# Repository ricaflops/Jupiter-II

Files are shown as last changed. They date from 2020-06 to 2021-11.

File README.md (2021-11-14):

# Jupiter-II
**Another Jupiter Ace computer clone**

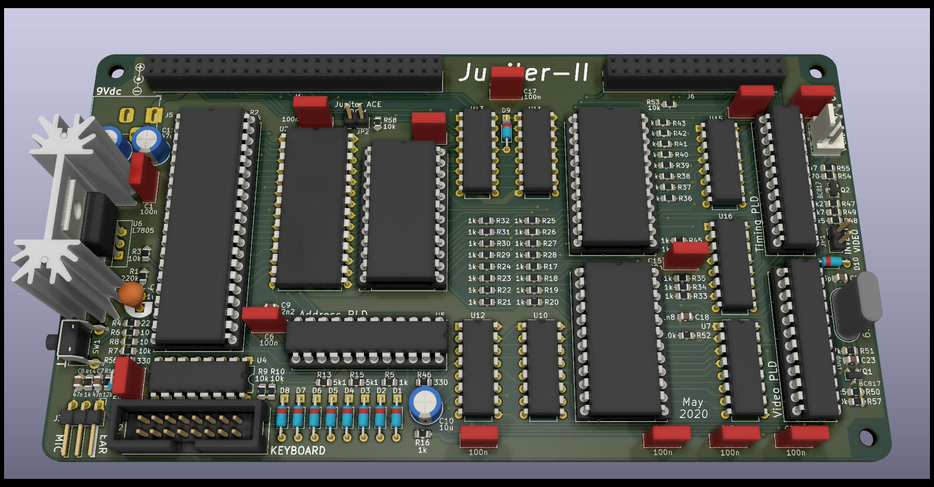
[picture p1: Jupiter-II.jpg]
Jupiter-II KiCAD 3D view

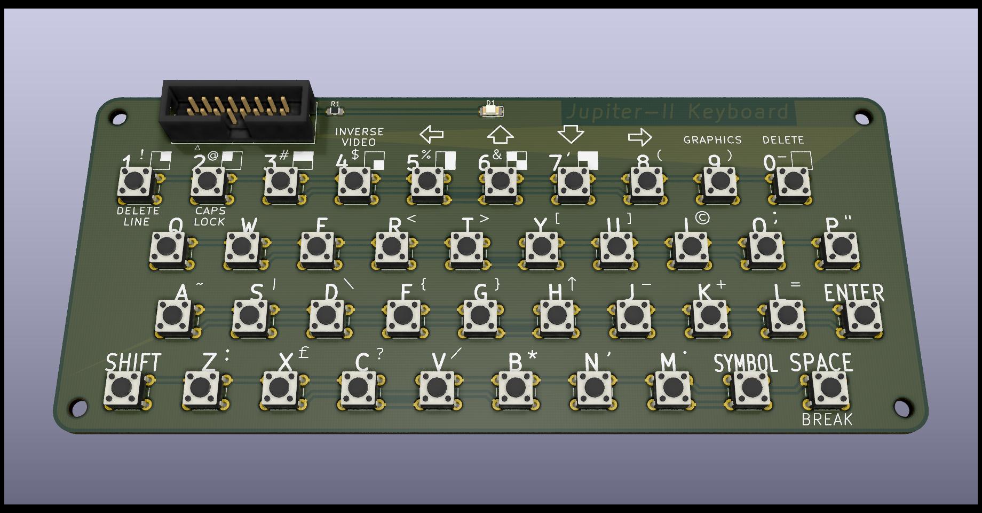
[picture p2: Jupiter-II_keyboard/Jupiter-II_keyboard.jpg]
Jupiter-II keyboard KiCAD 3D view


## Main differences from the original Jupiter Ace
* Buffered composite video output
* Reset button
* Inversed video jumper selection
* Two screen pages and two character sets area (selectable at the video expansion connector)
* Reduced chip count with PLDs replacing several TTL logic
* Additional signals in expansion connectors

For more information on the original Jupiter Ace computer and an extensive software collection visit [The Jupiter Ace Archive](http://jupiter-ace.co.uk/)

## The Jupiter-II Expansion
See the [Jupiter-II Expansion](https://github.com/ricaflops/Jupiter-II-Expansion) project for adding:
- Video Colour
- Programmable Sound Generator
- 128K paged RAM
- Serial Interface
- FORTH vocabulary extension (Color, Memory Paging, Sound Generator, etc.)

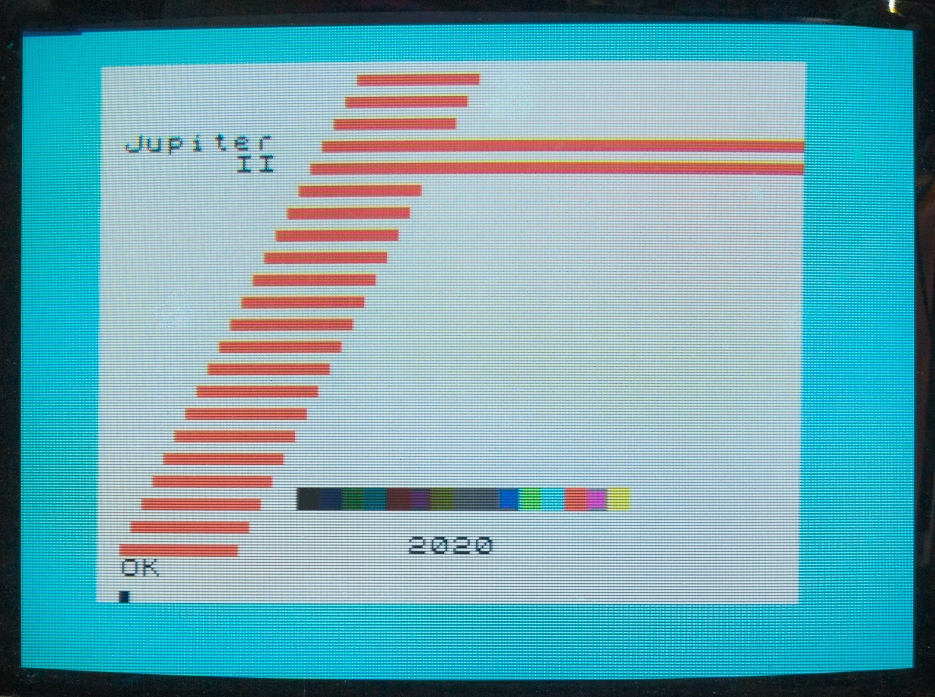
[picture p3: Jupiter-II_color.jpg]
Jupiter-II color expansion


# Jumper Settings

Inverse Video Jumper
- Jumper installed: Black text on white background (inversed)
- Jumper removed: White text on black background (default)

ROM image selection Jumper
- Jumper installed: Original Jupiter Ace 8K ROM image
- Jumper removed: Boot with the [Jupiter-II Expansion](https://github.com/ricaflops/Jupiter-II-Expansion)

The original Jupiter Ace 8K ROM image can be found at [The Jupiter Ace Archive](https://www.jupiter-ace.co.uk/).

# Connections

### Power Supply
Connect a 7.5Vdc to 9 Vdc x 1A power supply. Center pin is positive.

### A/V output
- pin 1: Audio Output (BEEP)
- pin 2: Common
- pin 3: Composite Video Output

The video standard is **60Hz NTSC** compatible but converting to 50Hz PAL by recoding the PLDs shall not be too difficult.

### Tape I/O
- pin 1: MIC output (for LOADing)
- pin 2: Common
- pin 3: EAR input (for SAVEing)

### Expansion
50 pin header connector (2x25 female).
Similar layout as the original Jupiter Ace with additional pins "-ROMSL" and "SPEAKER"

* pin 1:**GND** , pin 2:**GND**
* pin 3:**-INT** , pin 4:**GND**
* pin 5:**-NMI** , pin 6:**+9Vdc**
* pin 7:**-HALT** , pin 8:**+5Vdc**
* pin 9:**-MREQ** , pin 10:**-CLK**
* pin 11:**-IORQ** , pin 12:**A11**
* pin 13:**-RD** , pin 14:**A12**
* pin 15:**-WR** , pin 16:**A13**
* pin 17:**-BUSACK** , pin 18:**A14**
* pin 19:**-WAIT** , pin 20:**A15**
* pin 21:**-BUSRQ** , pin 22:**D4**
* pin 23:**-RESET** , pin 24:**D3**
* pin 25:**-M1** , pin 26:**D5**
* pin 27:**-RFSH** , pin 28:**A2**
* pin 29:**A6** , pin 30:**A10**
* pin 31:**A5** , pin 32:**A9**
* pin 33:**A4** , pin 34:**A8**
* pin 35:**A3** , pin 36:**A7**
* pin 37:**A1** , pin 38:**A0**
* pin 39:**D0** , pin 40:**D1**
* pin 41:**D2** , pin 42:**D6**
* pin 43:**D7** , pin 44:**-WE**
* pin 45:(n.c.) , pin 46:(n.c.)
* pin 47:**-ROMSL** , pin 48:**SPEAKER**
* pin 49:(n.c.) , pin 50:(n.c.)

(n.c.) means not connected

**-ROMSL** *(in)* Disables internal ROM chip when connected to +5V

**SPEAKER** *(out)* TTL level Speaker signal (BEEP)

### Video Expansion
30 pins header connector (2x15 female).
Similar layout as the original Jupiter Ace with some additional pins.

* pin 1:**VA3** , pin 2:**VA0**
* pin 3:**VA5** , pin 4:**VA4**
* pin 5:**VD2** , pin 6:**VD3**
* pin 7:**VD1** , pin 8:**VD4**
* pin 9:**VA6** , pin 10:**VD0**
* pin 11:**VA2** , pin 12:**VD7**
* pin 13:**-VRAMWR** , pin 14:**VD5**
* pin 15:**VA8** , pin 16:**VA7**
* pin 17:**VA9** , pin 18:**VA1**
* pin 19:**VD6** , pin 20:**-VLOAD**
* pin 21:**+5Vdc** , pin 22:**GND**
* pin 23:**-CPAGE** , pin 24:**-SPAGE**
* pin 25:**-SCRRAM** , pin 26:**-VSYNC**
* pin 27:**BORDER** , pin 28:**-HSYNC**
* pin 29:**LUMA** , pin 30:**BLANK**

**-VRAMWR** *(out)* Video RAM write enable

**-CPAGE** *(in)* Character Generator page selection

**-SPAGE** *(in)* Screen page selection

**-SCRRAM** *(out)* Screen RAM enabled

**-VSYNC** *(out)* Vertical Video Synch

**-HSYNC** *(out)* Horizontal Video Synch

**LUMA** *(out)* Video Luminance

**BLANK** *(out)* Video Blanking (retrace blanking)

## Tools used & file formats
* Designed with [Kicad](https://www.kicad.org/)
* Programmable Logic Devices coded in CUPL language (compiled with WinCupl available for free at [Microchip](https://www.microchip.com/))

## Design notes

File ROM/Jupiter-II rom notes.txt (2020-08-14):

Jupiter-II 16K ROM contains two images:
- Lower  8K: Original Jupiter Ace ROM image.
- Higher 8K: Patched image to call Expansion ROM initialization.

A board jumper is provided to select which image to boot:
- Jumpter installed: Original ROM image. Do not boot the Expansion ROM.
- Jumper removed: Patched ROM image. Includes Expansion ROM booting.

The patch is applied at address $008E of original ROM image:
    008E: C3 00 C0 00

Original code:
    008E: ED 56      IM 1      ; Set Interrupt mode 1
    0090: 18 09      JR $009B  ; Quit to FORTH

Patched code:
    008E: C3 00 C0   JP $C000  ; Redirect to XROM code
    0091: 00         NOP       ; Do nothing

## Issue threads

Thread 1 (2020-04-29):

Video

flypie, 2020-04-29:
Hi,
I had a look at your Ace and it looks very good. I'm doing a similar project I did find that I had to boost the composite sign before I could get a monitor to sync I used this circuit. https://jupiter-ace.co.uk/hardware_ebvdoboard.html I'm thinking of doing the similar for the audio out rather than use a speaker, not sure of what needed to get impedance correct.

ricaflops, 2020-04-29:
Hi,Thank You for the message.
I'm still waiting for the PCB to arrive from JLCPCB. It should take another month or two due to the current mail delays from China. Then I'll have several hours of fun validating those CUPL codes and making it work!

I did some protoboarding and tested the video circuit with a studio grade SONY video monitor and it worked fine. Should have experimented with a regular TV/monitor also before ordering the PCB. Thanks for the advice.

This project is intended to be a base for experimenting on Jupiter Ace expansions. I have some ideas to try and the type of expansion connectors chosen and the inclusion of more video signals shall make it easier to experiment on protoboard.
Many years ago I build a Jupiter Ace using wire-wrapping. You can check the actual pictures of it on the Jupiter Ace resource site. It was ugly but worked. Now that I'm reviving interest on this computer it is a good time to build it more adequately.
Just saw your Ace-2019 project in Github. Great work!
I specially like the use of dual port RAMs in video circuit.

Best regards,Ricardo.

    Em quarta-feira, 29 de abril de 2020 14:01:12 BRT, flypie <notifications@github.com> escreveu:

Hi,
I had a look at your Ace and it looks very good. I'm doing a similar project I did find that I had to boost the composite sign before I could get a monitor to sync I used this circuit. https://jupiter-ace.co.uk/hardware_ebvdoboard.html I'm thinking of doing the similar for the audio out rather than use a speaker, not sure of what needed to get impedance correct.

—
You are receiving this because you are subscribed to this thread.
Reply to this email directly, view it on GitHub, or unsubscribe.

flypie, 2020-04-30:
Hi

I order some SRAM from Wuhan earlier January, got it last week. I'm using the dual-port so that I don't have to use multiples of the video speed for the CPU.  There is the possibility with the faster Z80s to bypass the dived by 2 on the CPU and use the raw clock. With a few mods it should be possible to double the crystal and then dive by 2 for the video. The ACE3NOKB version I'm starting testing today will allow me to play with this using jumpers.
Your use of the 74HCT4040 is great I think I will do the same.
Are you going to stick with the DIP Z80? I've decided to use QFP for the CPU and ROM to save space and put 64k of RAM on the board using 2  IS61C256AL-12JLI.

ricaflops, 2020-05-01:
Hi,My option on vintage components (DIP Z80,ROM,RAM,etc) was to reuse as much components from my old inventary as I can, and keep costs low. The use of those old GALs was also motivated to easy the PCB design.

At this moment I want a working and compatible Jupiter Ace to experiment on interfacing ..and allow some nostalgic experience running those games on a real hardware as well.

I specifically want to experiment on sound with AY-3-8910, an UART to load/save via USB/RS232, color video, and test some ideas on memory paging and extended vocabulary ROM. Perhaps approaching something like an imaginary ZX-Spectrum competitor or what would be a backward compatible second generation Ace at that time. An Ace-Rainbow or Jupiter-Colour?

The clever approach in your project of freeing the video RAM from CPU syncing makes it possible I think to easily generate a VGA or HDMI video signal and use modern monitors. And perhaps even enable higher resolution video by increasing video RAM size and some changes in the original ROM code.
Your project is very inspiring for me and there is a lot to learn from it. Keep the nice work.

-RL
    Em quinta-feira, 30 de abril de 2020 10:11:15 BRT, flypie <notifications@github.com> escreveu:

Hi

I order some SRAM from Wuhan earlier January, got it last week. I'm using the dual-port so that I don't have to use multiples of the video speed for the CPU. There is the possibility with the faster Z80s to bypass the dived by 2 on the CPU and use the raw clock. With a few mods it should be possible to double the crystal and then dive by 2 for the video. The ACE3NOKB version I'm starting testing today will allow me to play with this using jumpers.
Your use of the 74HCT4040 is great I think I will do the same.
Are you going to stick with the DIP Z80? I've decided to use QFP for the CPU and ROM to save space and put 64k of RAM on the board using 2 IS61C256AL-12JLI.

—
You are receiving this because you commented.

Reply to this email directly, view it on GitHub, or unsubscribe.

flypie, 2020-05-03:
Hi

The recreating the ace is what I did first to make sure that I know how it all worked.

It is worth looking at the Z180 as it has an MMU inboard and it is still made by Zilog it would mean ROM changes to handle the interrupts. But with a 1Meg address space placing a 64k for VGA will out of the base 64k and paging the sections in to write to them would make sense. It would also mean that it might be possible to reduce the CPU VDG conflict.

For other expansion, it might be worth looking at[ PCMIA/Compact flash](https://en.wikipedia.org/wiki/PC_Card). It uses 5v TTL levels. Someone has done some work on [this ](https://z80project.wordpress.com/2015/07/06/z80-8-bit-compact-flash-card-interface-part-1/).

I'm beginning to think the best place for any ROM expansion is the top 8K to avoid having to rewrite the tape loader.

Are you aware of [SymbOS](https://en.wikipedia.org/wiki/SymbOS) The base hardware requirements might be a good target point?

I'm glad you find the project useful it was my hope to make it easier to design and build their own machines from readily available components.

ricaflops, 2020-05-04:
Thanks for the suggestions on Z180. will read the docs.

I agree on the ROM expansion position at the highest addresses.Lower addresses shall be RAM for the user FORTH dictionary to grown into and to keep some compatibility with the original Ace.

I am planning for the following memory organization for a 128K RAM + 16K ROM expansion:
(ASCII diagram follows)

       pg0   pg1   pg2   pg3  
    -|-----|-----|-----|-----|
FFFF | 16K |     |     |     |
C000 | ROM | 32K | 32K | 32K |
    -+-----| RAM | RAM | RAM |
BFFF | 16K | pg1 | pg2 | pg3 |
8000 | RAM |     |     |     |
    -+-----+-----+-----+-----|
7FFF |        Fixed          |
4000 |       16K RAM         |
    -+-----------------------|
3FFF |   (unexpanded Ace)    |
0000 |_______________________|

That gives a good fixed 16K RAM (non-paged) contiguous space for the user FORTH dictionary, a page of 16K RAM + 16K ROM, and more 3 pages of 32K RAM.

The plan is use the available two 8-bit I/O ports of AY-3-8910 sound generator for memory paging and screen colour register.
Port A: Screen colour INK/PAPER registers (4-bit each)
Port B: Memory paging (2-bits), Screen paging (1-bit), Charset page (1-bit), (remaining 4-bit to be defined yet)

Never looked at SymbOS before. I will check that.

About the audio output impedance. I never thinked too much on that.. lazy of me!
But I can remedy that.

The Wikipedia https://en.wikipedia.org/wiki/Line_level states that a typical consumer audio equipment line input impedance is around 10k ohms and the nominal amplitude is 0.89Vpp full range.

TTL LS family output impedance can be estimated around 100 ohm or so.
That allow us to reduce the TTL 5Vpp to a compatible 0.88Vpp using a 4.7K+1k voltage divider without a hard load on TTL.

A decoupling capacitor in series is needed as a high-pass filter to block DC current.
That filter cut-off frequency (-3dB point) is: f = 1/(2*pi*R*C).
Lets choose that frequency to at least 2Hz. That is one decade below the average hearing threshold of 20Hz.
Assuming the 10K ohm as the line input impedance: C = 1/(2*pi*10k*2) = 7.96uF (minimum)
I will choose 10uF.(ASCII diagram follows)
                        10uF
From TTL----[4.7k]---+---|(---- to Audio amplifier
                     |  +
     GND----[ 1k ]---+

Just did a lab test with a function generator and a small amplifier. Worked fine with a nice flat response from 10Hz and above.
May increase that 4.7k resistor to reduce volume. Maybe a 6.8k would result in a softer audio.

The EAR and MIC circuits also deserves better attention as it was originally designed to work with very different audio lines. Working on that too.

    Em domingo, 3 de maio de 2020 10:48:36 BRT, flypie <notifications@github.com> escreveu:

Hi

The recreating the ace is what I did first to make sure that I know how it all worked.

It is worth looking at the Z180 as it has an MMU inboard and it is still made by Zilog it would mean ROM changes to handle the interrupts. But with a 1Meg address space placing a 64k for VGA will out of the base 64k and paging the sections in to write to them would make sense. It would also mean that it might be possible to reduce the CPU VDG conflict.

For other expansion, it might be worth looking at PCMIA/Compact flash. It uses 5v TTL levels. Someone has done some work on this .

I'm beginning to think the best place for any ROM expansion is the top 8K to avoid having to rewrite the tape loader.

Are you aware of SymbOS The base hardware requirements might be a good target point?

I'm glad you find the project useful it was my hope to make it easier to design and build their own machines from readily available components.

—
You are receiving this because you commented.

Reply to this email directly, view it on GitHub, or unsubscribe.

flypie, 2020-05-04:
Hi

Thanks for the audio info, I do not get on with analogue.

Someone has done this. The ROM model is good and I the Video Model, only using one dual-port RAM is a lot cheaper.

https://www.tindie.com/products/tynemouthsw/minstrel-4th-z80-computer-kit/

ricaflops, 2020-05-11:
Board was received two days ago and hardware were tested/debugged.
Updated circuit uploaded. It includes some important corrections and a better/robust video output.
Thanks for the suggestion.And yes, that tynemouthsw product is very well thought. I like that they kept software compatibility.

    Em segunda-feira, 4 de maio de 2020 18:30:57 BRT, flypie <notifications@github.com> escreveu:

Hi

Thanks for the audio info, I do not get on with analogue.

Someone has done this. The ROM model is good and I the Video Model, only using one dual-port RAM is a lot cheaper.

https://www.tindie.com/products/tynemouthsw/minstrel-4th-z80-computer-kit/

—
You are receiving this because you commented.

Reply to this email directly, view it on GitHub, or unsubscribe.

flypie, 2020-05-11:
Hi,
Good to hear.

John BradleyTel: 07896 839635Skype: flypie125 125B Grove StreetEdge Hill Liverpool L7 7AF

    On Monday, 11 May 2020, 03:42:57 BST, Ricardo Fernandes Lopes <notifications@github.com> wrote:

Board was received two days ago and hardware were tested/debugged.
Updated circuit uploaded. It includes some important corrections and a better/robust video output.
Thanks for the suggestion.And yes, that tynemouthsw product is very well thought. I like that they kept software compatibility.

 Em segunda-feira, 4 de maio de 2020 18:30:57 BRT, flypie <notifications@github.com> escreveu:

Hi

Thanks for the audio info, I do not get on with analogue.

Someone has done this. The ROM model is good and I the Video Model, only using one dual-port RAM is a lot cheaper.

https://www.tindie.com/products/tynemouthsw/minstrel-4th-z80-computer-kit/

—
You are receiving this because you commented.

Reply to this email directly, view it on GitHub, or unsubscribe.
—
You are receiving this because you authored the thread.
Reply to this email directly, view it on GitHub, or unsubscribe.

Closed 2020-05-11.

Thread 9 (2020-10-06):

.Schematic depends on missing libraries

MrBlinky, 2020-10-06:
opening a schematic reports missing libraries:

rfl_memory.lib
rfl_pld.lib

Request: Export schematic to PDF using plot for easy reference

ricaflops, 2020-10-06:
extra library and PDF schematic uploaded

ricaflops, 2020-10-06:
Hi, Mr.Blinky
Library and PDF schematic uploaded.
Thank you!Ricardo

    Em terça-feira, 6 de outubro de 2020 07:36:00 BRT, Mr.Blinky <notifications@github.com> escreveu:

opening a schematic reports missing libraries:

rfl_memory.lib
rfl_pld.lib

Request: Export schematic to PDF using plot for easy reference

—
You are receiving this because you are subscribed to this thread.
Reply to this email directly, view it on GitHub, or unsubscribe.

MrBlinky, 2020-10-07:
Hi Ricardo,

Thank you for adding the library files and schematics.

Closed 2020-10-06.

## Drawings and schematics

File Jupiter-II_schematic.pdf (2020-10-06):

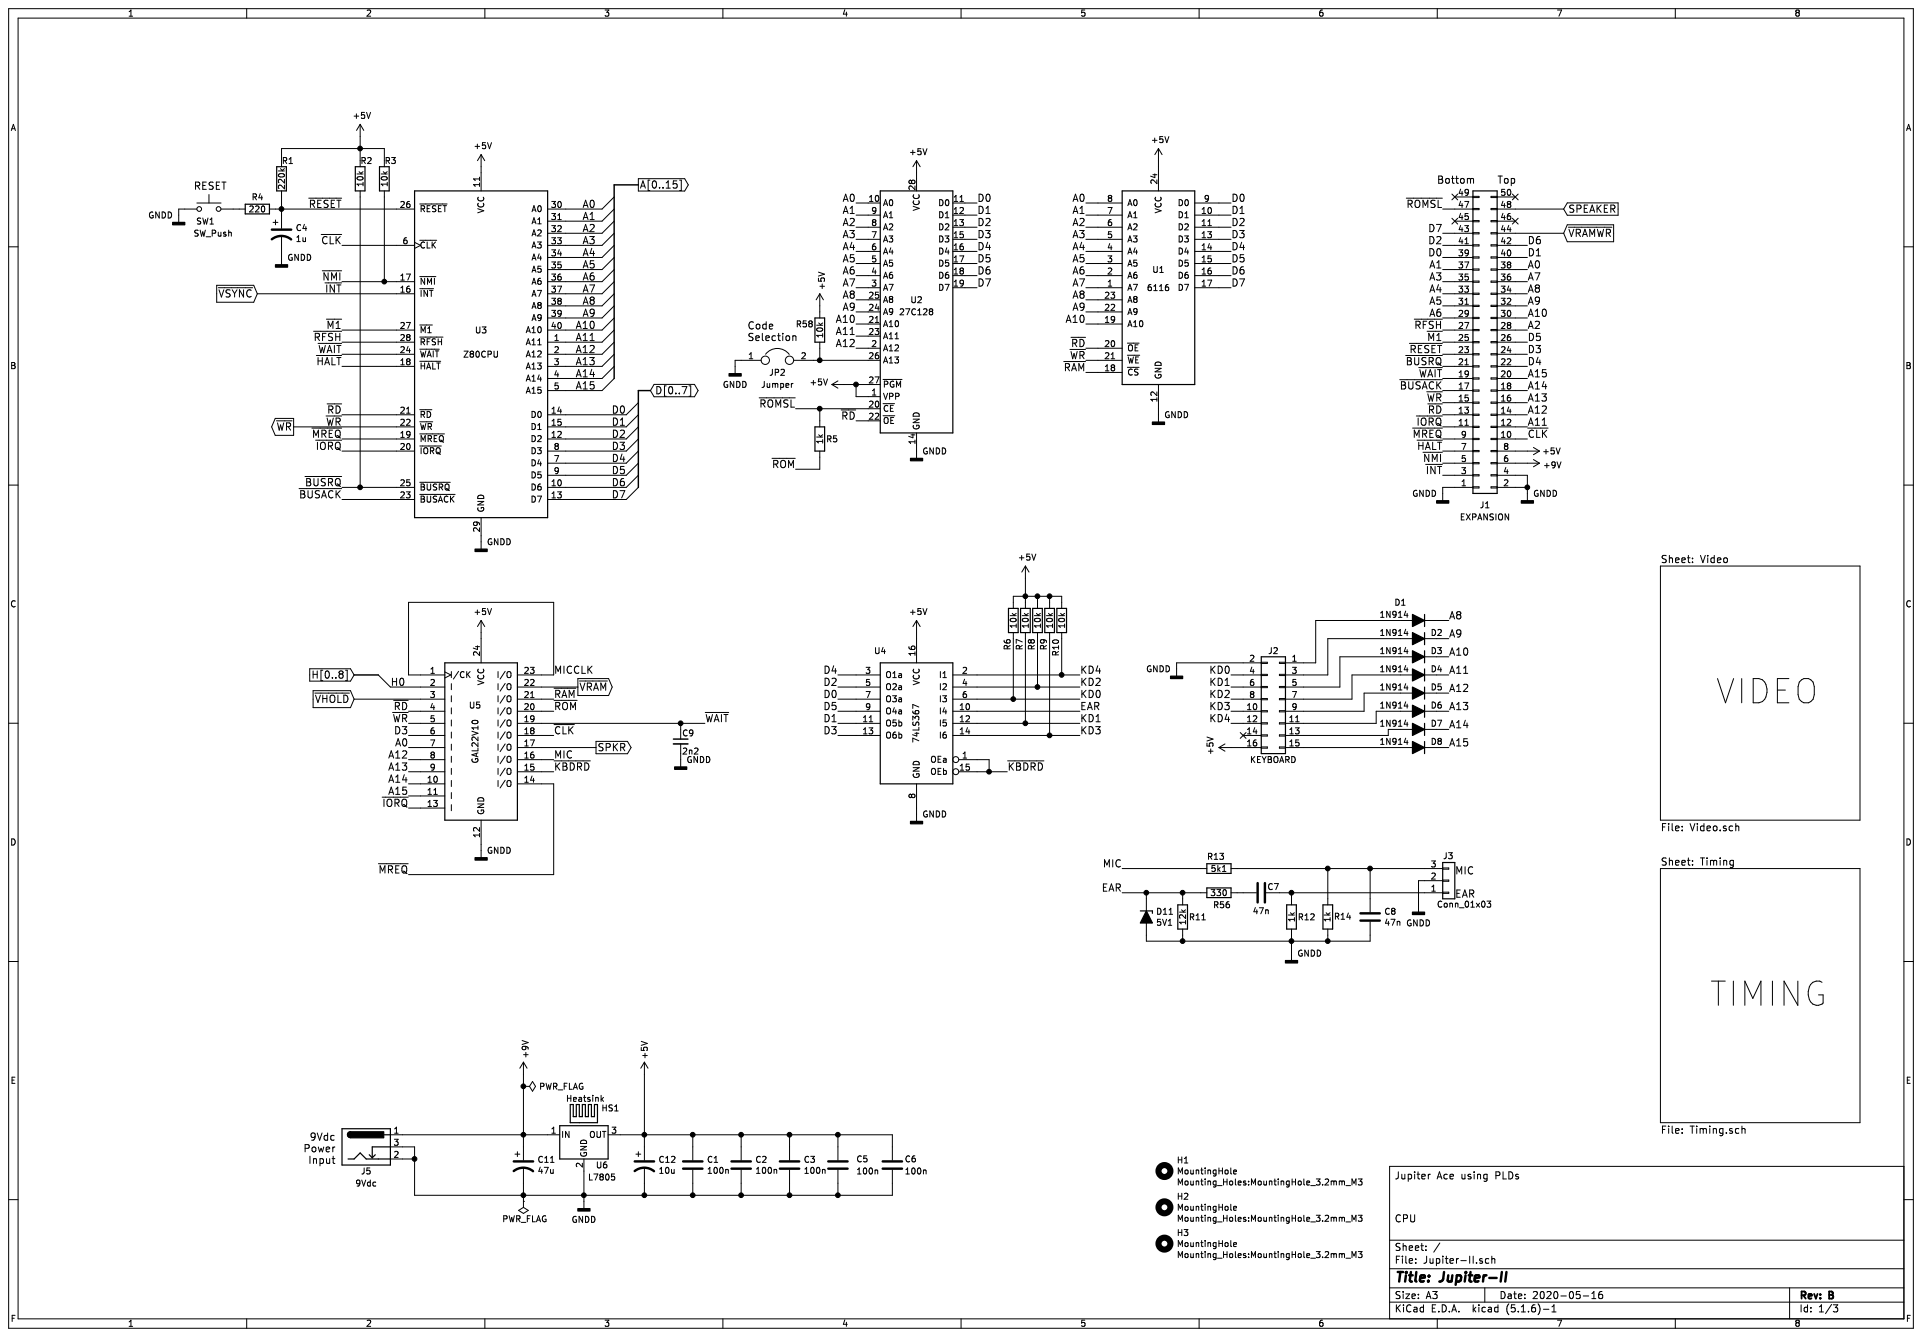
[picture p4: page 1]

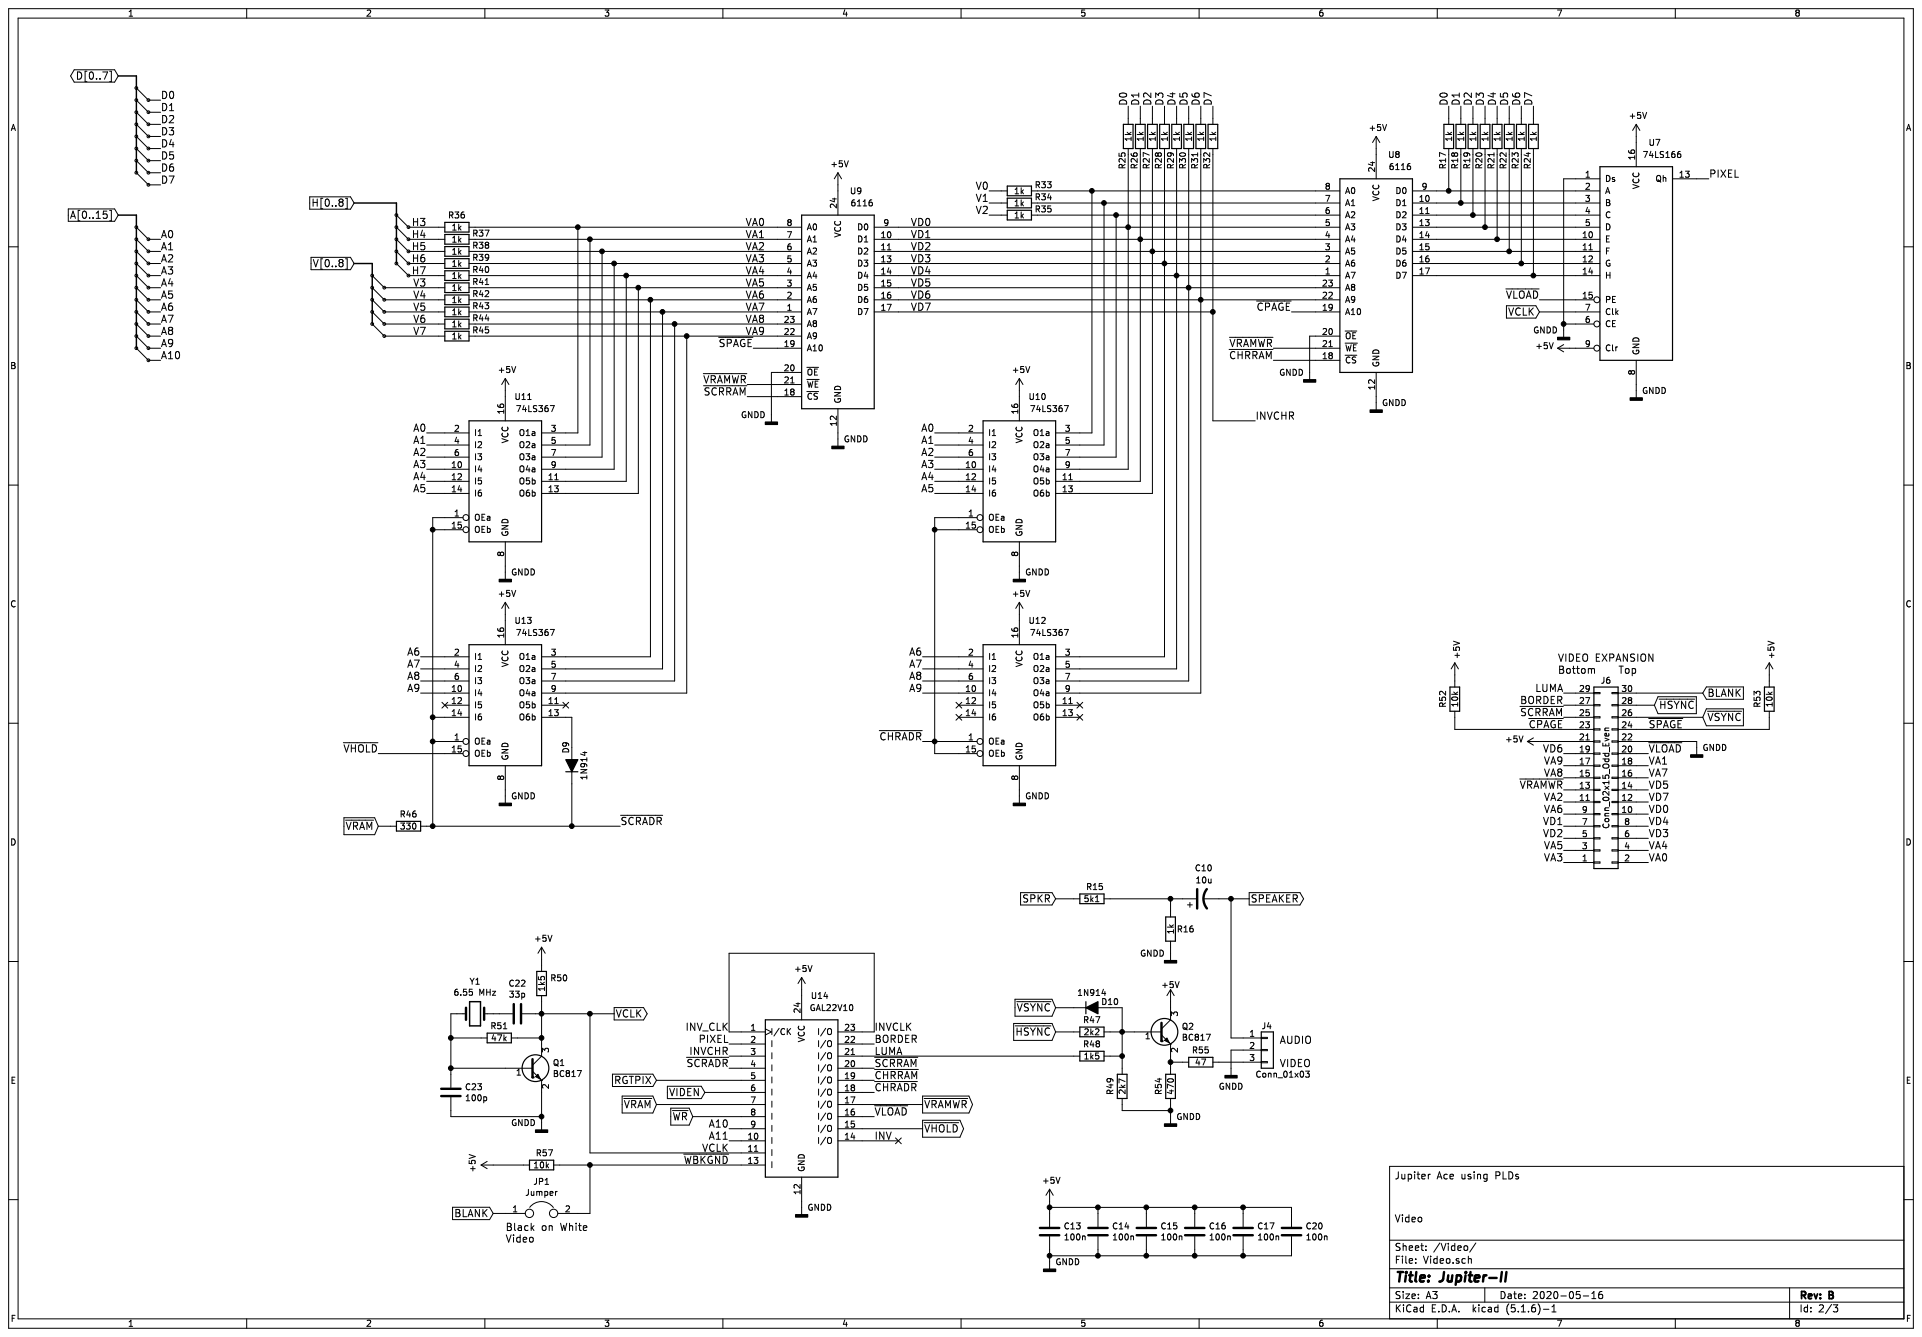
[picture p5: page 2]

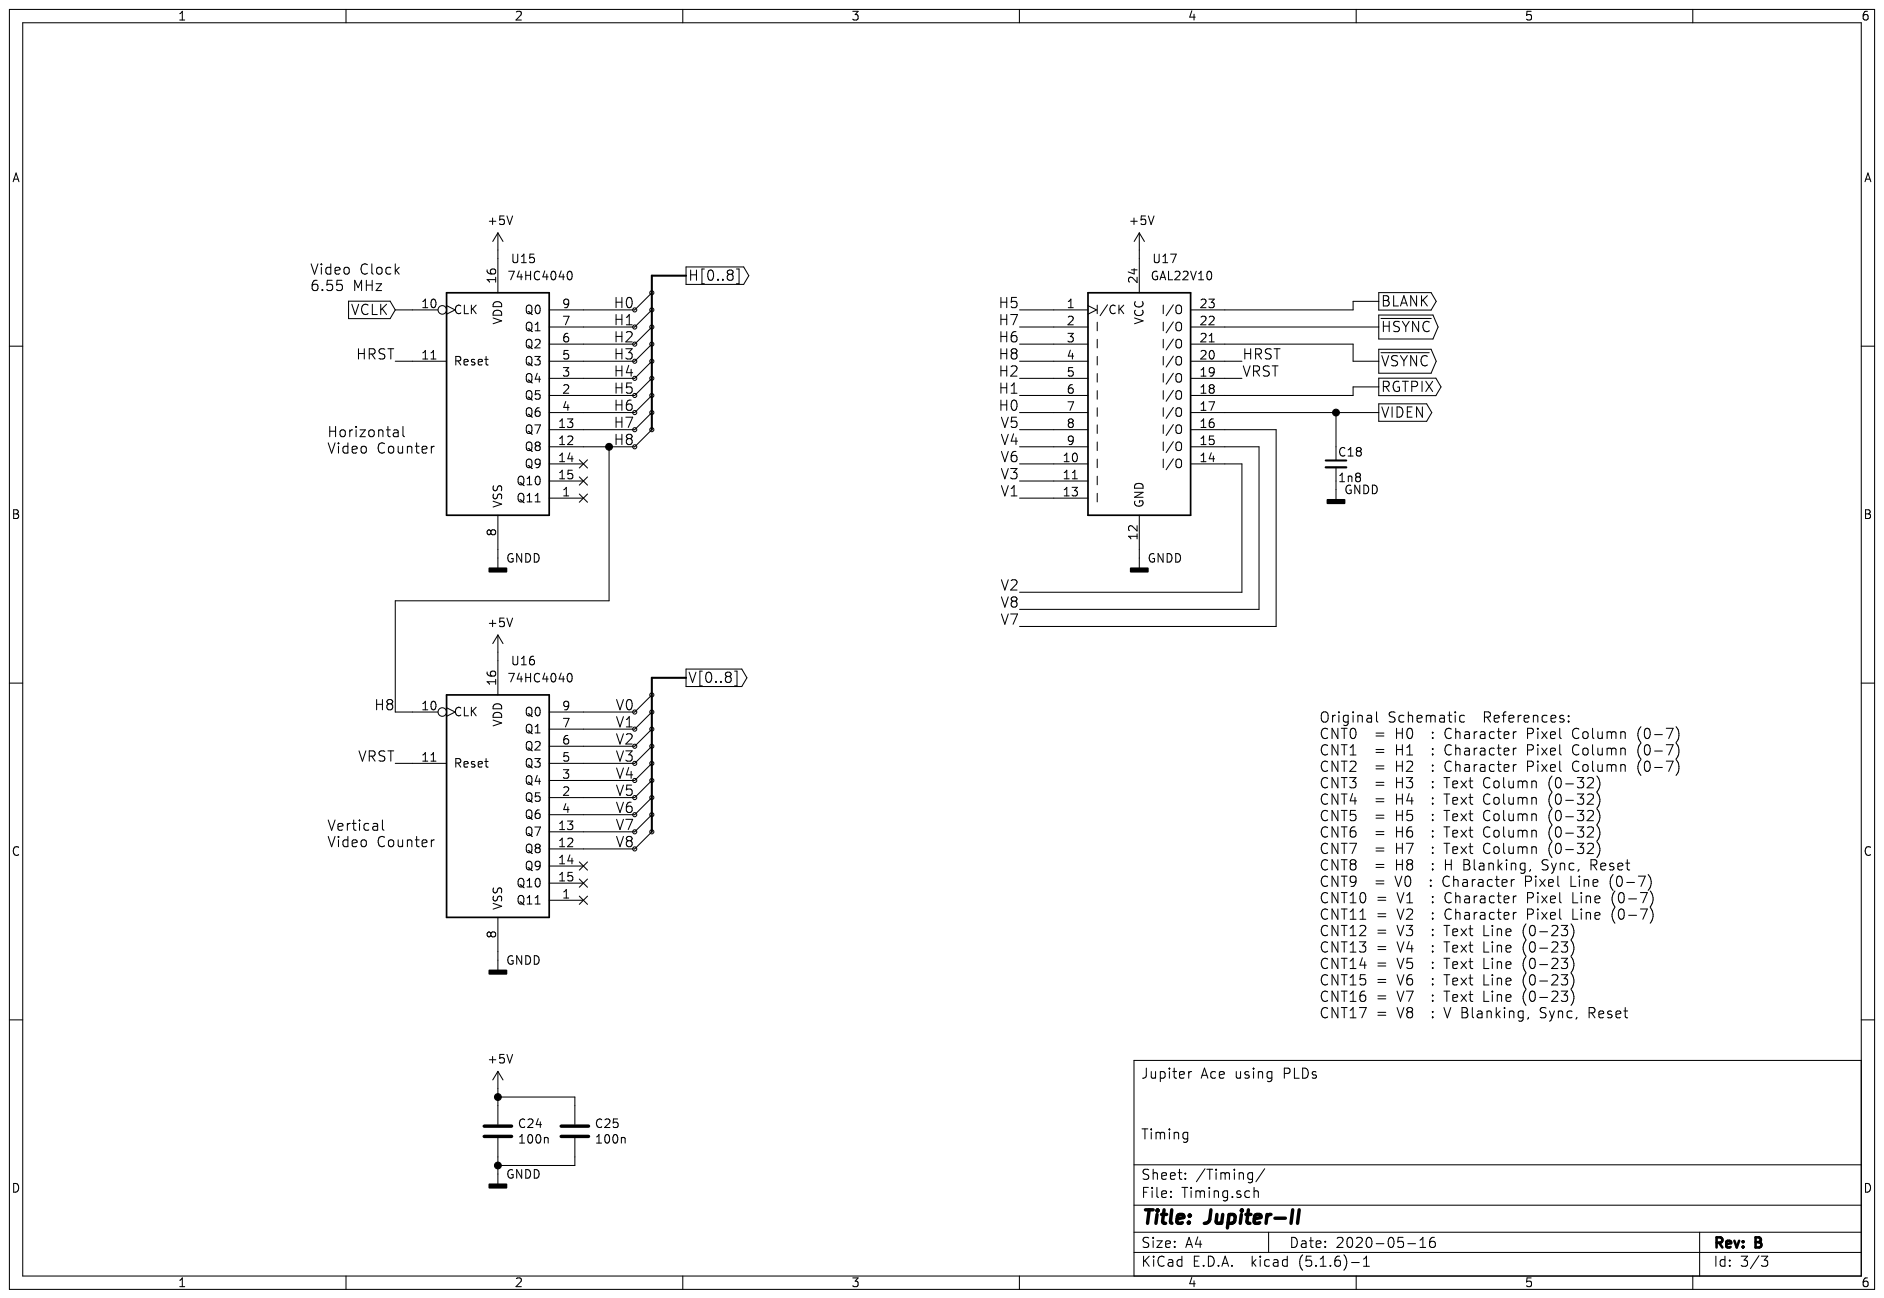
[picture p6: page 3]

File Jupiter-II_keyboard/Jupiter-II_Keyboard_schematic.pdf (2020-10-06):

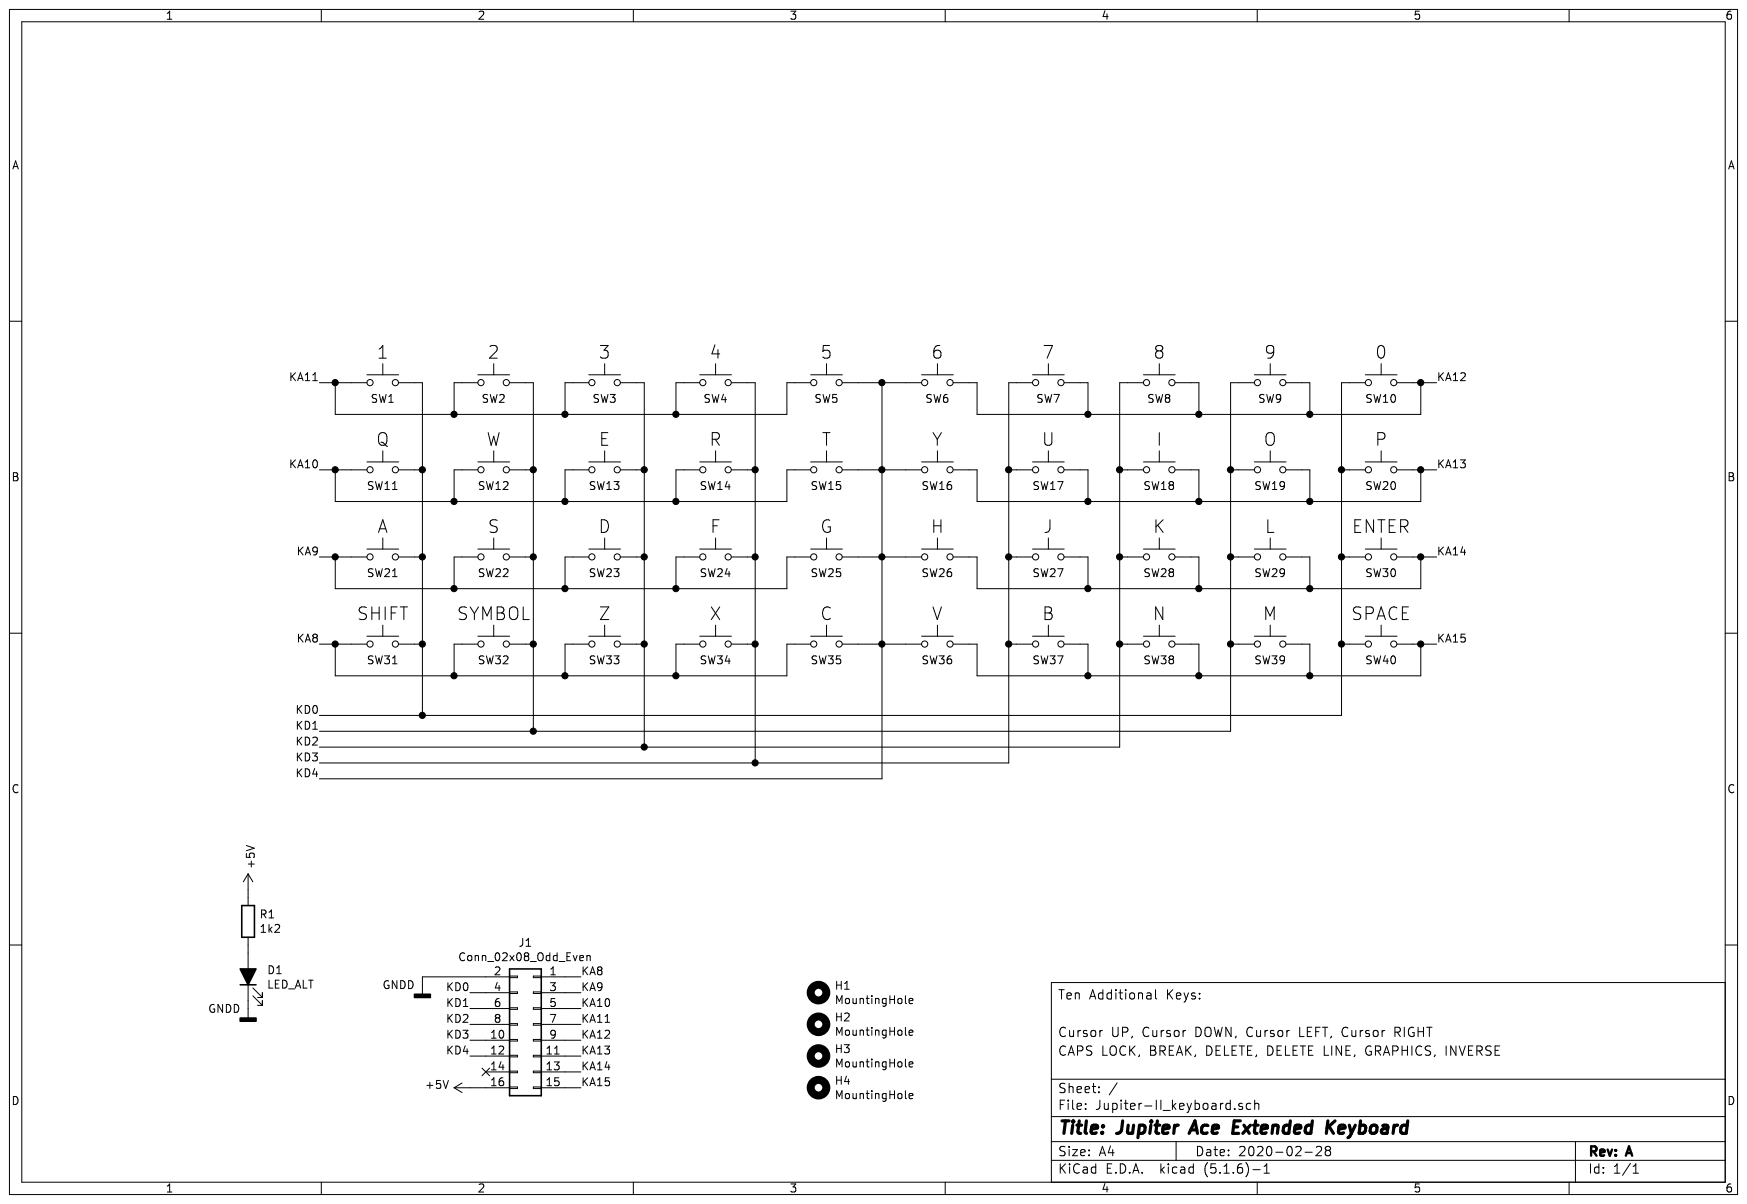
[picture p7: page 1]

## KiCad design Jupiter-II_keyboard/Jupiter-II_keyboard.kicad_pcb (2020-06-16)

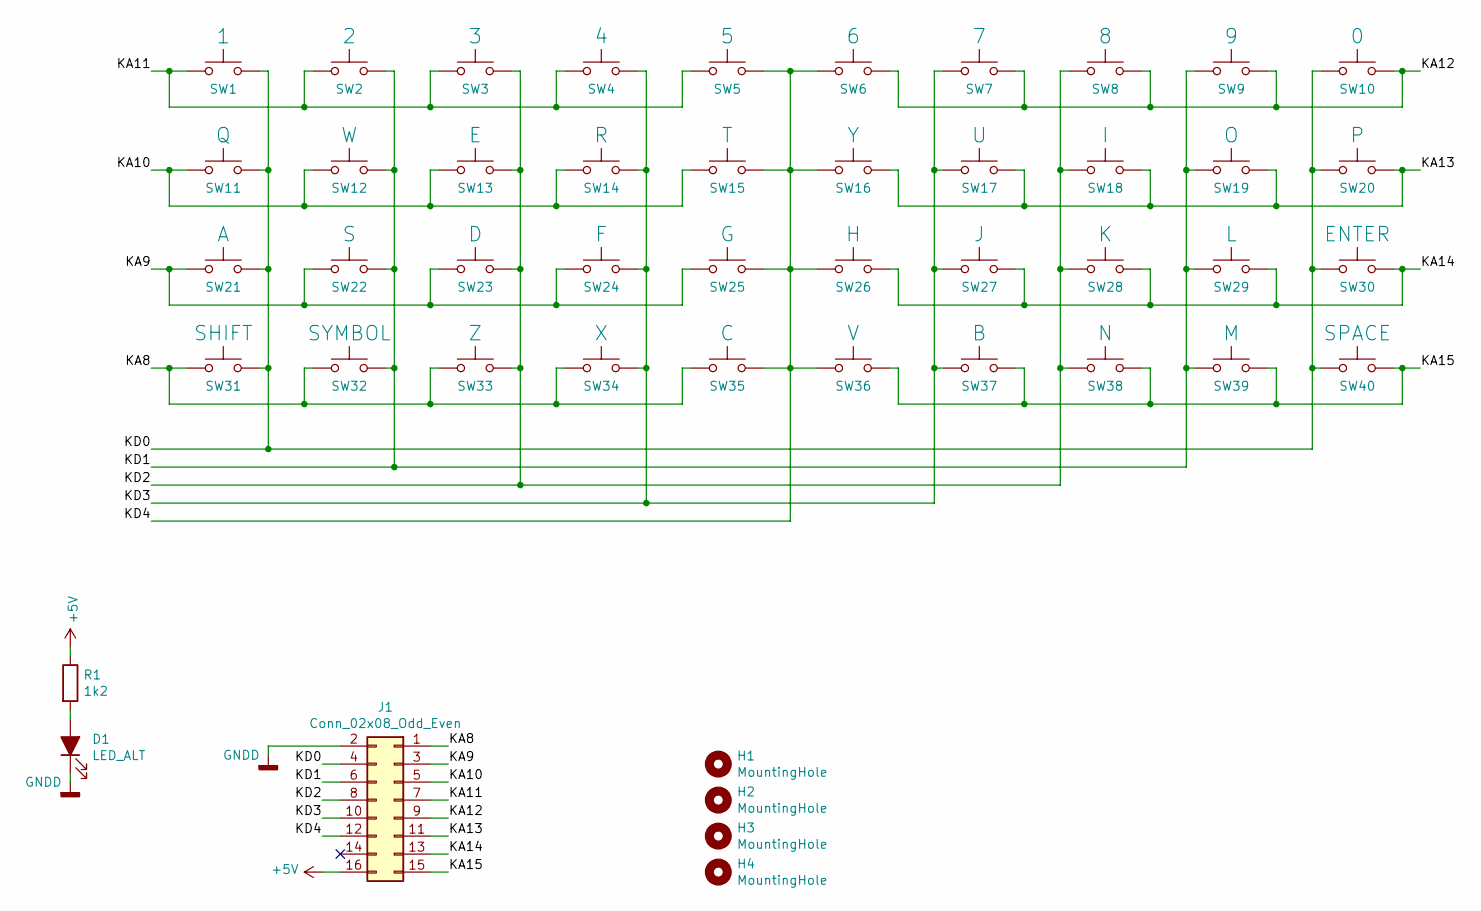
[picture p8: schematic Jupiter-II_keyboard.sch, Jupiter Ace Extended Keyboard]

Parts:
D1: LED_ALT; LED_1206_3216Metric_Pad1.42x1.75mm_HandSolder
H1, H2, H3, H4: MountingHole; MountingHole_3.2mm_M3
J1: Conn_02x08_Odd_Even; IDC-Header_2x08_P2.54mm_Vertical
R1: 1k2; R_0805_2012Metric_Pad1.15x1.40mm_HandSolder
SW1: 1; SW_PUSH_6mm
SW2: 2; SW_PUSH_6mm
SW3: 3; SW_PUSH_6mm
SW4: 4; SW_PUSH_6mm
SW5: 5; SW_PUSH_6mm
SW6: 6; SW_PUSH_6mm
SW7: 7; SW_PUSH_6mm
SW8: 8; SW_PUSH_6mm
SW9: 9; SW_PUSH_6mm
SW10: 0; SW_PUSH_6mm
SW11: Q; SW_PUSH_6mm
SW12: W; SW_PUSH_6mm
SW13: E; SW_PUSH_6mm
SW14: R; SW_PUSH_6mm
SW15: T; SW_PUSH_6mm
SW16: Y; SW_PUSH_6mm
SW17: U; SW_PUSH_6mm
SW18: I; SW_PUSH_6mm
SW19: O; SW_PUSH_6mm
SW20: P; SW_PUSH_6mm
SW21: A; SW_PUSH_6mm
SW22: S; SW_PUSH_6mm
SW23: D; SW_PUSH_6mm
SW24: F; SW_PUSH_6mm
SW25: G; SW_PUSH_6mm
SW26: H; SW_PUSH_6mm
SW27: J; SW_PUSH_6mm
SW28: K; SW_PUSH_6mm
SW29: L; SW_PUSH_6mm
SW30: ENTER; SW_PUSH_6mm
SW31: SHIFT; SW_PUSH_6mm
SW32: SYMBOL; SW_PUSH_6mm
SW33: Z; SW_PUSH_6mm
SW34: X; SW_PUSH_6mm
SW35: C; SW_PUSH_6mm
SW36: V; SW_PUSH_6mm
SW37: B; SW_PUSH_6mm
SW38: N; SW_PUSH_6mm
SW39: M; SW_PUSH_6mm
SW40: SPACE; SW_PUSH_6mm

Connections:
+5V: J1.16, R1.1
/KA8: J1.1, SW31.1, SW32.1, SW33.1, SW34.1, SW35.1
/KA9: J1.3, SW21.1, SW22.1, SW23.1, SW24.1, SW25.1
/KA10: J1.5, SW11.1, SW12.1, SW13.1, SW14.1, SW15.1
/KA11: J1.7, SW1.1, SW2.1, SW3.1, SW4.1, SW5.1
/KA12: J1.9, SW6.1, SW7.1, SW8.1, SW9.1, SW10.1
/KA13: J1.11, SW16.1, SW17.1, SW18.1, SW19.1, SW20.1
/KA14: J1.13, SW26.1, SW27.1, SW28.1, SW29.1, SW30.1
/KA15: J1.15, SW36.1, SW37.1, SW38.1, SW39.1, SW40.1
/KD0: J1.4, SW1.2, SW10.2, SW11.2, SW20.2, SW21.2, SW30.2, SW31.2, SW40.2
/KD1: J1.6, SW2.2, SW9.2, SW12.2, SW19.2, SW22.2, SW29.2, SW32.2, SW39.2
/KD2: J1.8, SW3.2, SW8.2, SW13.2, SW18.2, SW23.2, SW28.2, SW33.2, SW38.2
/KD3: J1.10, SW4.2, SW7.2, SW14.2, SW17.2, SW24.2, SW27.2, SW34.2, SW37.2
/KD4: J1.12, SW5.2, SW6.2, SW15.2, SW16.2, SW25.2, SW26.2, SW35.2, SW36.2
GNDD: D1.1 (K), J1.2
unnamed: D1.2 (A), R1.2

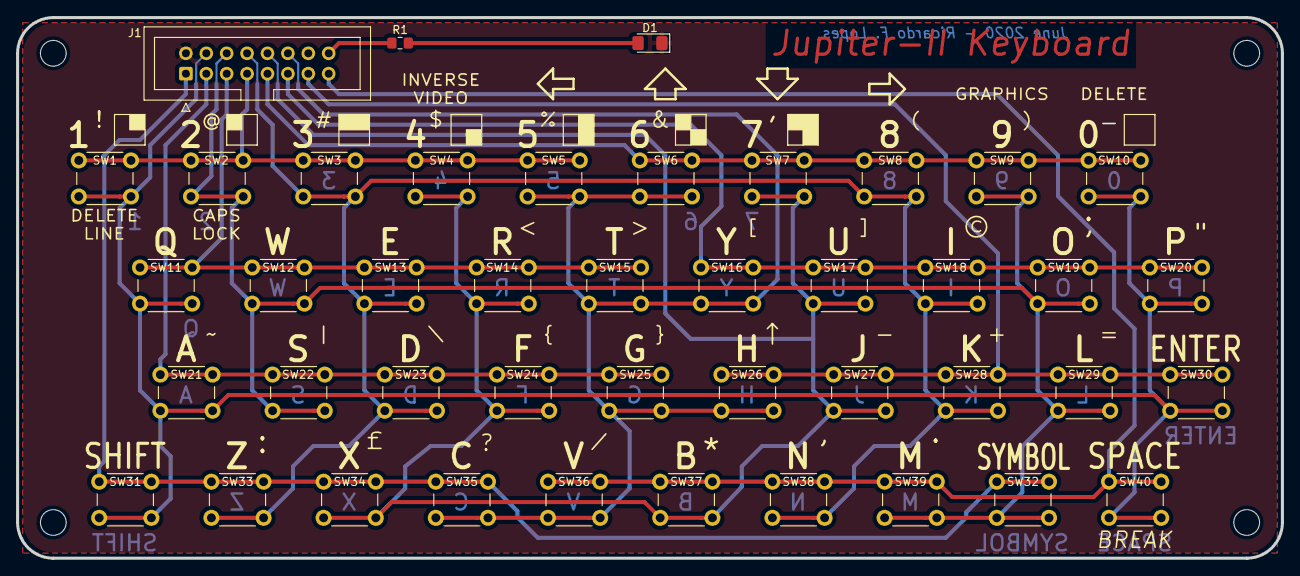
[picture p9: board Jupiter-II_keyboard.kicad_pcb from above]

Board: 2 copper layers, 157.5 x 67.3 mm, 47 parts (0 on the bottom side), 16 nets.

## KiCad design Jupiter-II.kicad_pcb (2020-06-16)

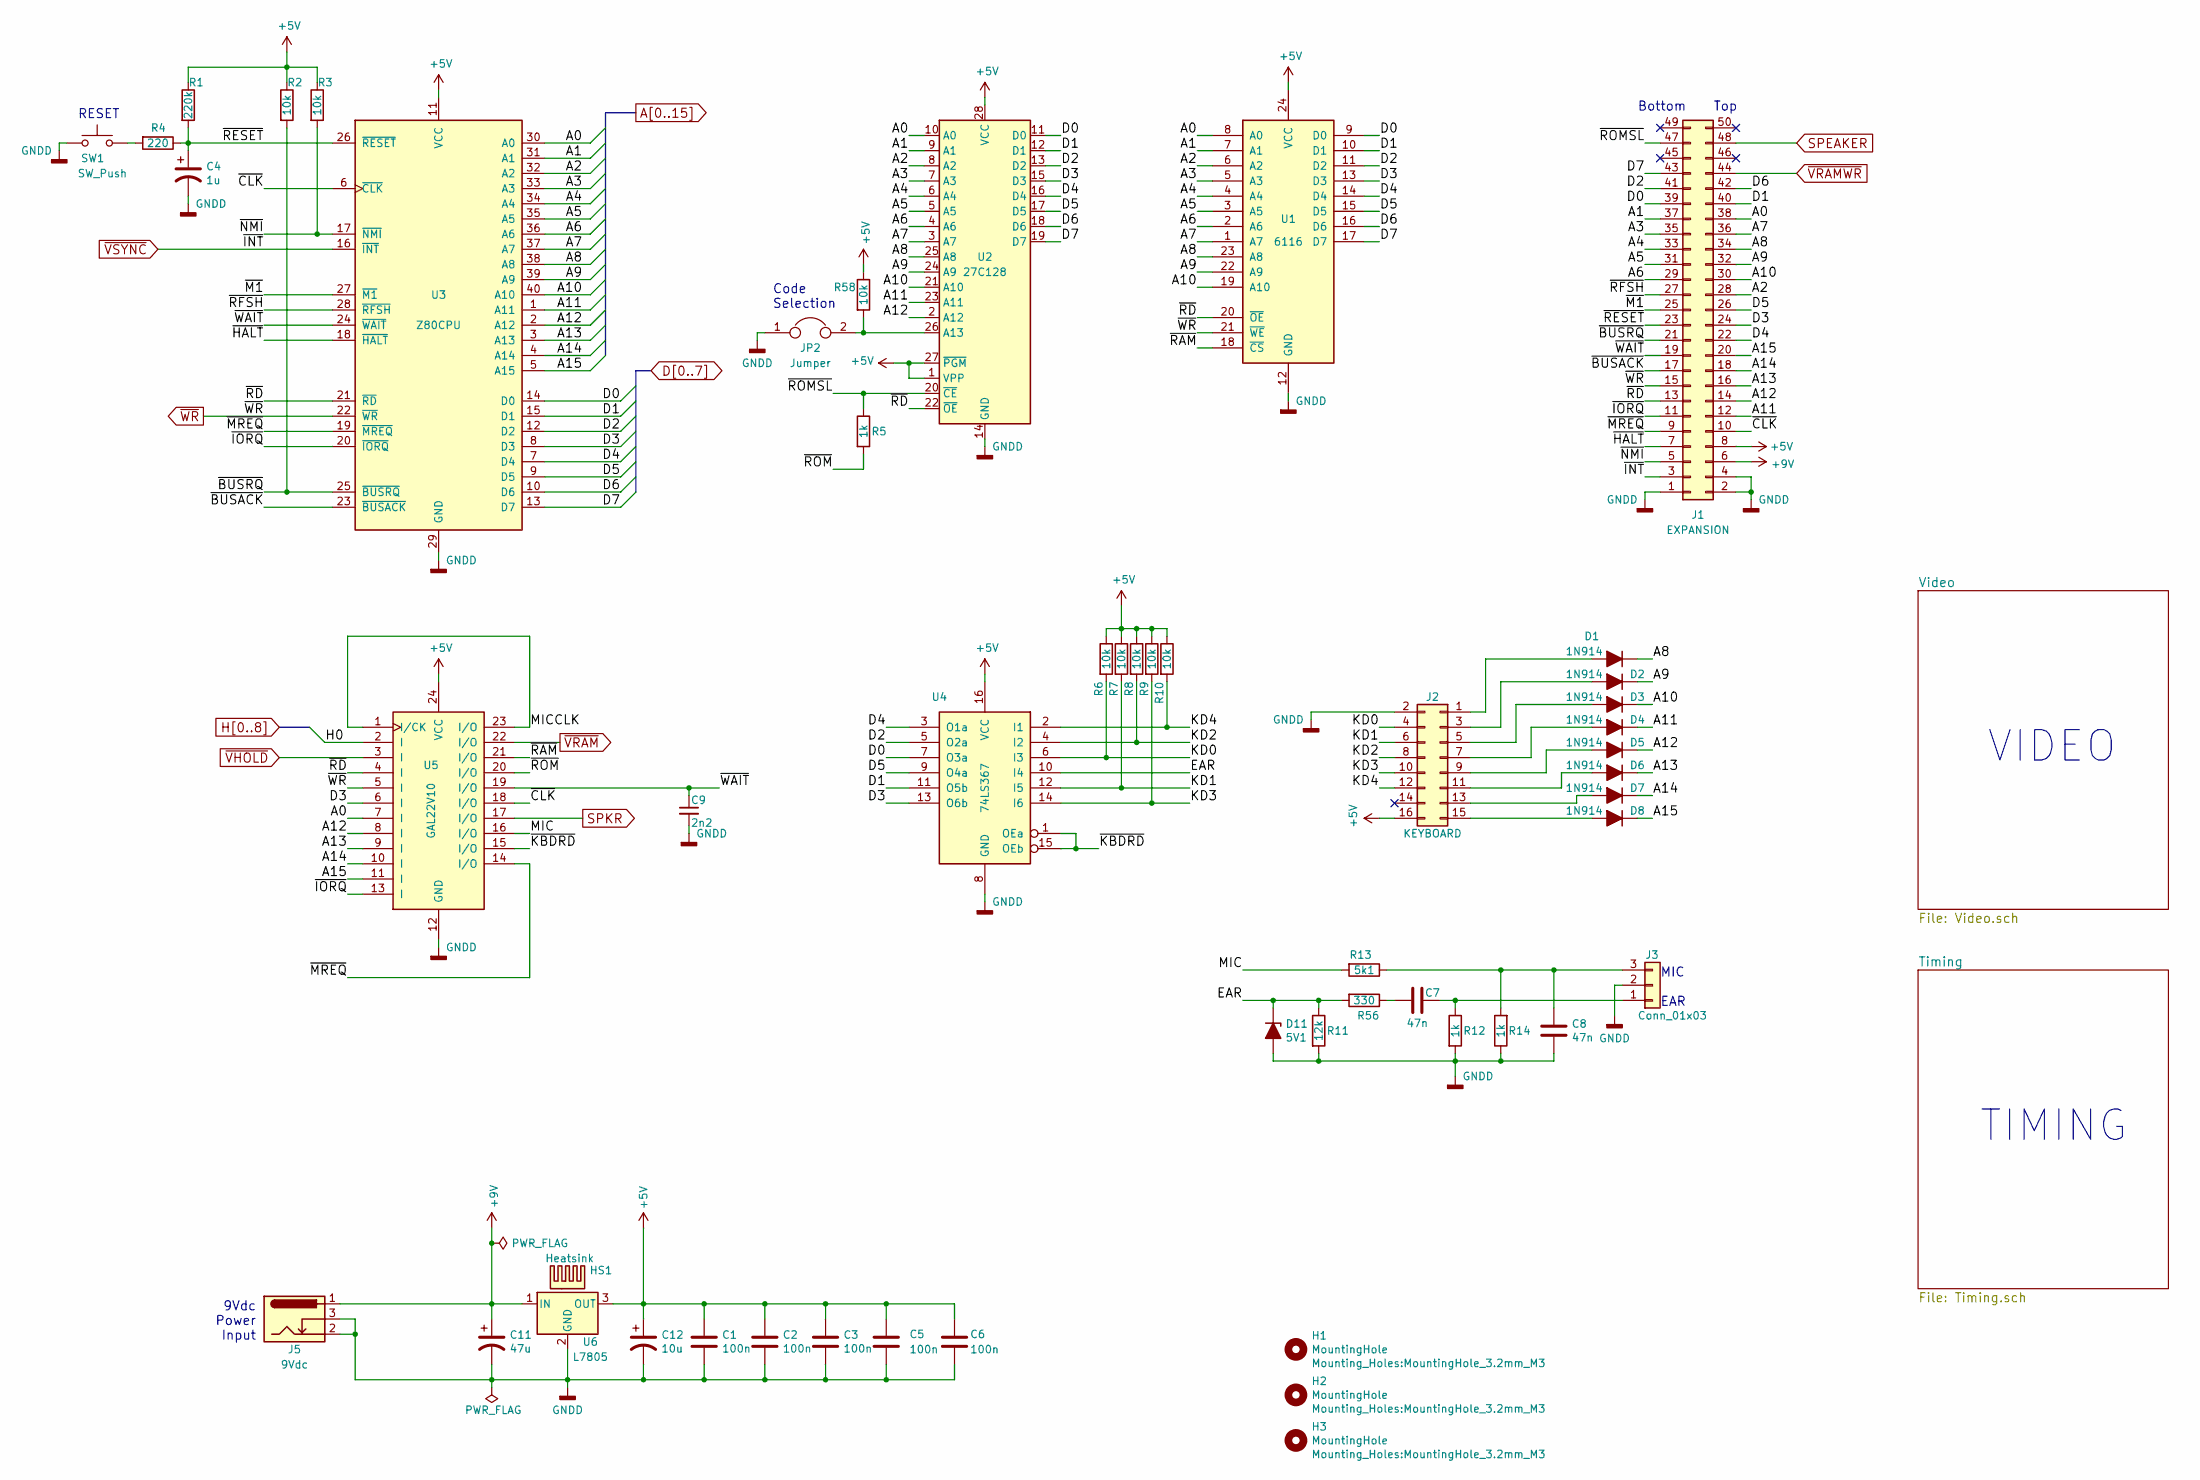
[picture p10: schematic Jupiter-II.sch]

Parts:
C1, C2, C3, C5, C6: 100n; C_Rect_L7.0mm_W2.5mm_P5.00mm
C4: 1u; CP_Radial_D6.3mm_P2.50mm
C7, C8: 47n; C_0805_2012Metric_Pad1.15x1.40mm_HandSolder
C9: 2n2; C_0805_2012Metric_Pad1.15x1.40mm_HandSolder
C11: 47u; CP_Radial_D6.3mm_P2.50mm
C12: 10u; CP_Radial_D6.3mm_P2.50mm
D1, D2, D3, D4, D5, D6, D7, D8: 1N914; D_DO-35_SOD27_P7.62mm_Horizontal
D11: 5V1; D_DO-35_SOD27_P2.54mm_Vertical_KathodeUp
H1, H2, H3: MountingHole; MountingHole_3.2mm_M3
HS1: Heatsink; Heatsink_35x12mm_2xFixation1.5mm
J1: EXPANSION; Socket_Strip_Straight_2x25_Pitch2.54mm
J2: KEYBOARD; Multicomp_MC9A12-1634_2x08x2.54mm_Straight
J3: Conn_01x03; Pin_Header_Angled_1x03_Pitch2.54mm
J5: 9Vdc; BarrelJack_Horizontal
JP2: Jumper; PinHeader_1x02_P2.54mm_Vertical
R1: 220k; R_0805_2012Metric_Pad1.15x1.40mm_HandSolder
R2, R3, R6, R7, R8, R9, R10, R58: 10k; R_0805_2012Metric_Pad1.15x1.40mm_HandSolder
R4: 220; R_0805_2012Metric_Pad1.15x1.40mm_HandSolder
R5, R12, R14: 1k; R_0805_2012Metric_Pad1.15x1.40mm_HandSolder
R11: 12k; R_0805_2012Metric_Pad1.15x1.40mm_HandSolder
R13: 5k1; R_0805_2012Metric_Pad1.15x1.40mm_HandSolder
R56: 330; R_0805_2012Metric_Pad1.15x1.40mm_HandSolder
SW1: SW_Push; SW_Tactile_SPST_Angled_PTS645Vx58-2LFS
U1: 6116; DIP-24_W15.24mm_Socket
U2: 27C128; DIP-28_W15.24mm
U3: Z80CPU; DIP-40_W15.24mm_Socket
U4: 74LS367; DIP-16_W7.62mm
U5: GAL22V10; DIP-24_W7.62mm_Socket
U6: L7805; TO-220-3_Vertical

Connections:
+5V: C1.1, C2.1, C3.1, C5.1, C6.1, C12.1, J1.8, J2.16, R1.1, R2.1, R3.1, R6.1, R7.1, R8.1, R9.1, R10.1, R58.1, U1.24 (VCC), U2.1 (VPP), U2.27 (~PGM), U2.28 (VCC), U3.11 (VCC), U4.16 (VCC), U5.24 (VCC), U6.3 (OUT); also elsewhere on the board
+9V: C11.1, J1.6, J5.1, U6.1 (IN)
/EAR: D11.1 (K), R11.1, R56.2, U4.10 (I4)
/KD0: J2.4, R6.2, U4.6 (I3)
/KD1: J2.6, R7.2, U4.12 (I5)
/KD2: J2.8, R8.2, U4.4 (I2)
/KD3: J2.10, R9.2, U4.14 (I6)
/KD4: J2.12, R10.2, U4.2 (I1)
/MIC: R13.2, U5.16 (I/O)
/MICCLK: U5.1 (I/CK), U5.23 (I/O)
/~BUSACK: J1.17, U3.23 (~BUSACK~)
/~BUSRQ: J1.21, R2.2, U3.25 (~BUSRQ~)
/~CLK: J1.10, U3.6 (~CLK~), U5.18 (I/O)
/~HALT: J1.7, U3.18 (~HALT~)
/~IORQ: J1.11, U3.20 (~IORQ~), U5.13 (I)
/~KBDRD: U4.1 (OEa), U4.15 (OEb), U5.15 (I/O)
/~M1: J1.25, U3.27 (~M1~)
/~MREQ: J1.9, U3.19 (~MREQ~), U5.14 (I/O)
/~NMI: J1.5, R3.2, U3.17 (~NMI~)
/~RAM: U1.18 (~CS), U5.21 (I/O)
/~RD: J1.13, U1.20 (~OE), U2.22 (~OE), U3.21 (~RD~), U5.4 (I)
/~RESET: C4.1, J1.23, R1.2, R4.1, U3.26 (~RESET~)
/~RFSH: J1.27, U3.28 (~RFSH~)
/~ROM: R5.2, U5.20 (I/O)
/~ROMSL: J1.47, R5.1, U2.20 (~CE)
/~WAIT: C9.1, J1.19, U3.24 (~WAIT~), U5.19 (I/O)
A0: J1.38, U1.8 (A0), U2.10 (A0), U3.30 (A0), U5.7 (I); also elsewhere on the board
A1: J1.37, U1.7 (A1), U2.9 (A1), U3.31 (A1); also elsewhere on the board
A2: J1.28, U1.6 (A2), U2.8 (A2), U3.32 (A2); also elsewhere on the board
A3: J1.35, U1.5 (A3), U2.7 (A3), U3.33 (A3); also elsewhere on the board
A4: J1.33, U1.4 (A4), U2.6 (A4), U3.34 (A4); also elsewhere on the board
A5: J1.31, U1.3 (A5), U2.5 (A5), U3.35 (A5); also elsewhere on the board
A6: J1.29, U1.2 (A6), U2.4 (A6), U3.36 (A6); also elsewhere on the board
A7: J1.36, U1.1 (A7), U2.3 (A7), U3.37 (A7); also elsewhere on the board
A8: D1.1 (K), J1.34, U1.23 (A8), U2.25 (A8), U3.38 (A8); also elsewhere on the board
A9: D2.1 (K), J1.32, U1.22 (A9), U2.24 (A9), U3.39 (A9); also elsewhere on the board
A10: D3.1 (K), J1.30, U1.19 (A10), U2.21 (A10), U3.40 (A10); also elsewhere on the board
A11: D4.1 (K), J1.12, U2.23 (A11), U3.1 (A11); also elsewhere on the board
A12: D5.1 (K), J1.14, U2.2 (A12), U3.2 (A12), U5.8 (I)
A13: D6.1 (K), J1.16, U3.3 (A13), U5.9 (I)
A14: D7.1 (K), J1.18, U3.4 (A14), U5.10 (I)
A15: D8.1 (K), J1.20, U3.5 (A15), U5.11 (I)
D0: J1.39, U1.9 (D0), U2.11 (D0), U3.14 (D0), U4.7 (O3a); also elsewhere on the board
D1: J1.40, U1.10 (D1), U2.12 (D1), U3.15 (D1), U4.11 (O5b); also elsewhere on the board
D2: J1.41, U1.11 (D2), U2.13 (D2), U3.12 (D2), U4.5 (O2a); also elsewhere on the board
D3: J1.24, U1.13 (D3), U2.15 (D3), U3.8 (D3), U4.13 (O6b), U5.6 (I); also elsewhere on the board
D4: J1.22, U1.14 (D4), U2.16 (D4), U3.7 (D4), U4.3 (O1a); also elsewhere on the board
D5: J1.26, U1.15 (D5), U2.17 (D5), U3.9 (D5), U4.9 (O4a); also elsewhere on the board
D6: J1.42, U1.16 (D6), U2.18 (D6), U3.10 (D6); also elsewhere on the board
D7: J1.43, U1.17 (D7), U2.19 (D7), U3.13 (D7); also elsewhere on the board
GNDD: C1.2, C2.2, C3.2, C4.2, C5.2, C6.2, C8.2, C9.2, C11.2, C12.2, D11.2 (A), J1.1, J1.2, J1.4, J2.2, J3.2, J5.2, J5.3, JP2.1, R11.2, R12.2, R14.1, SW1.1, U1.12 (GND), U2.14 (GND), U3.29 (GND), U4.8 (GND), U5.12 (GND), U6.2 (GND); also elsewhere on the board
H0: U5.2 (I); also elsewhere on the board
unnamed: C7.1, J3.1, R12.1
unnamed: C7.2, R56.1
unnamed: C8.1, J3.3, R13.1, R14.2
unnamed: D1.2 (A), J2.1
unnamed: D2.2 (A), J2.3
unnamed: D3.2 (A), J2.5
unnamed: D4.2 (A), J2.7
unnamed: D5.2 (A), J2.9
unnamed: D6.2 (A), J2.11
unnamed: D7.2 (A), J2.13
unnamed: D8.2 (A), J2.15
unnamed: JP2.2, R58.2, U2.26 (A13)
unnamed: R4.2, SW1.2
SPEAKER: J1.48; also elsewhere on the board
SPKR: U5.17 (I/O); also elsewhere on the board
~VHOLD: U5.3 (I); also elsewhere on the board
~VRAM: U5.22 (I/O); also elsewhere on the board
~VRAMWR: J1.44; also elsewhere on the board
~VSYNC: J1.3, U3.16 (~INT~); also elsewhere on the board
~WR: J1.15, U1.21 (~WE), U3.22 (~WR~), U5.5 (I); also elsewhere on the board

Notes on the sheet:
RESET
TIMING
VIDEO
Bottom Top
9Vdc Power Input
MIC EAR
Code Selection

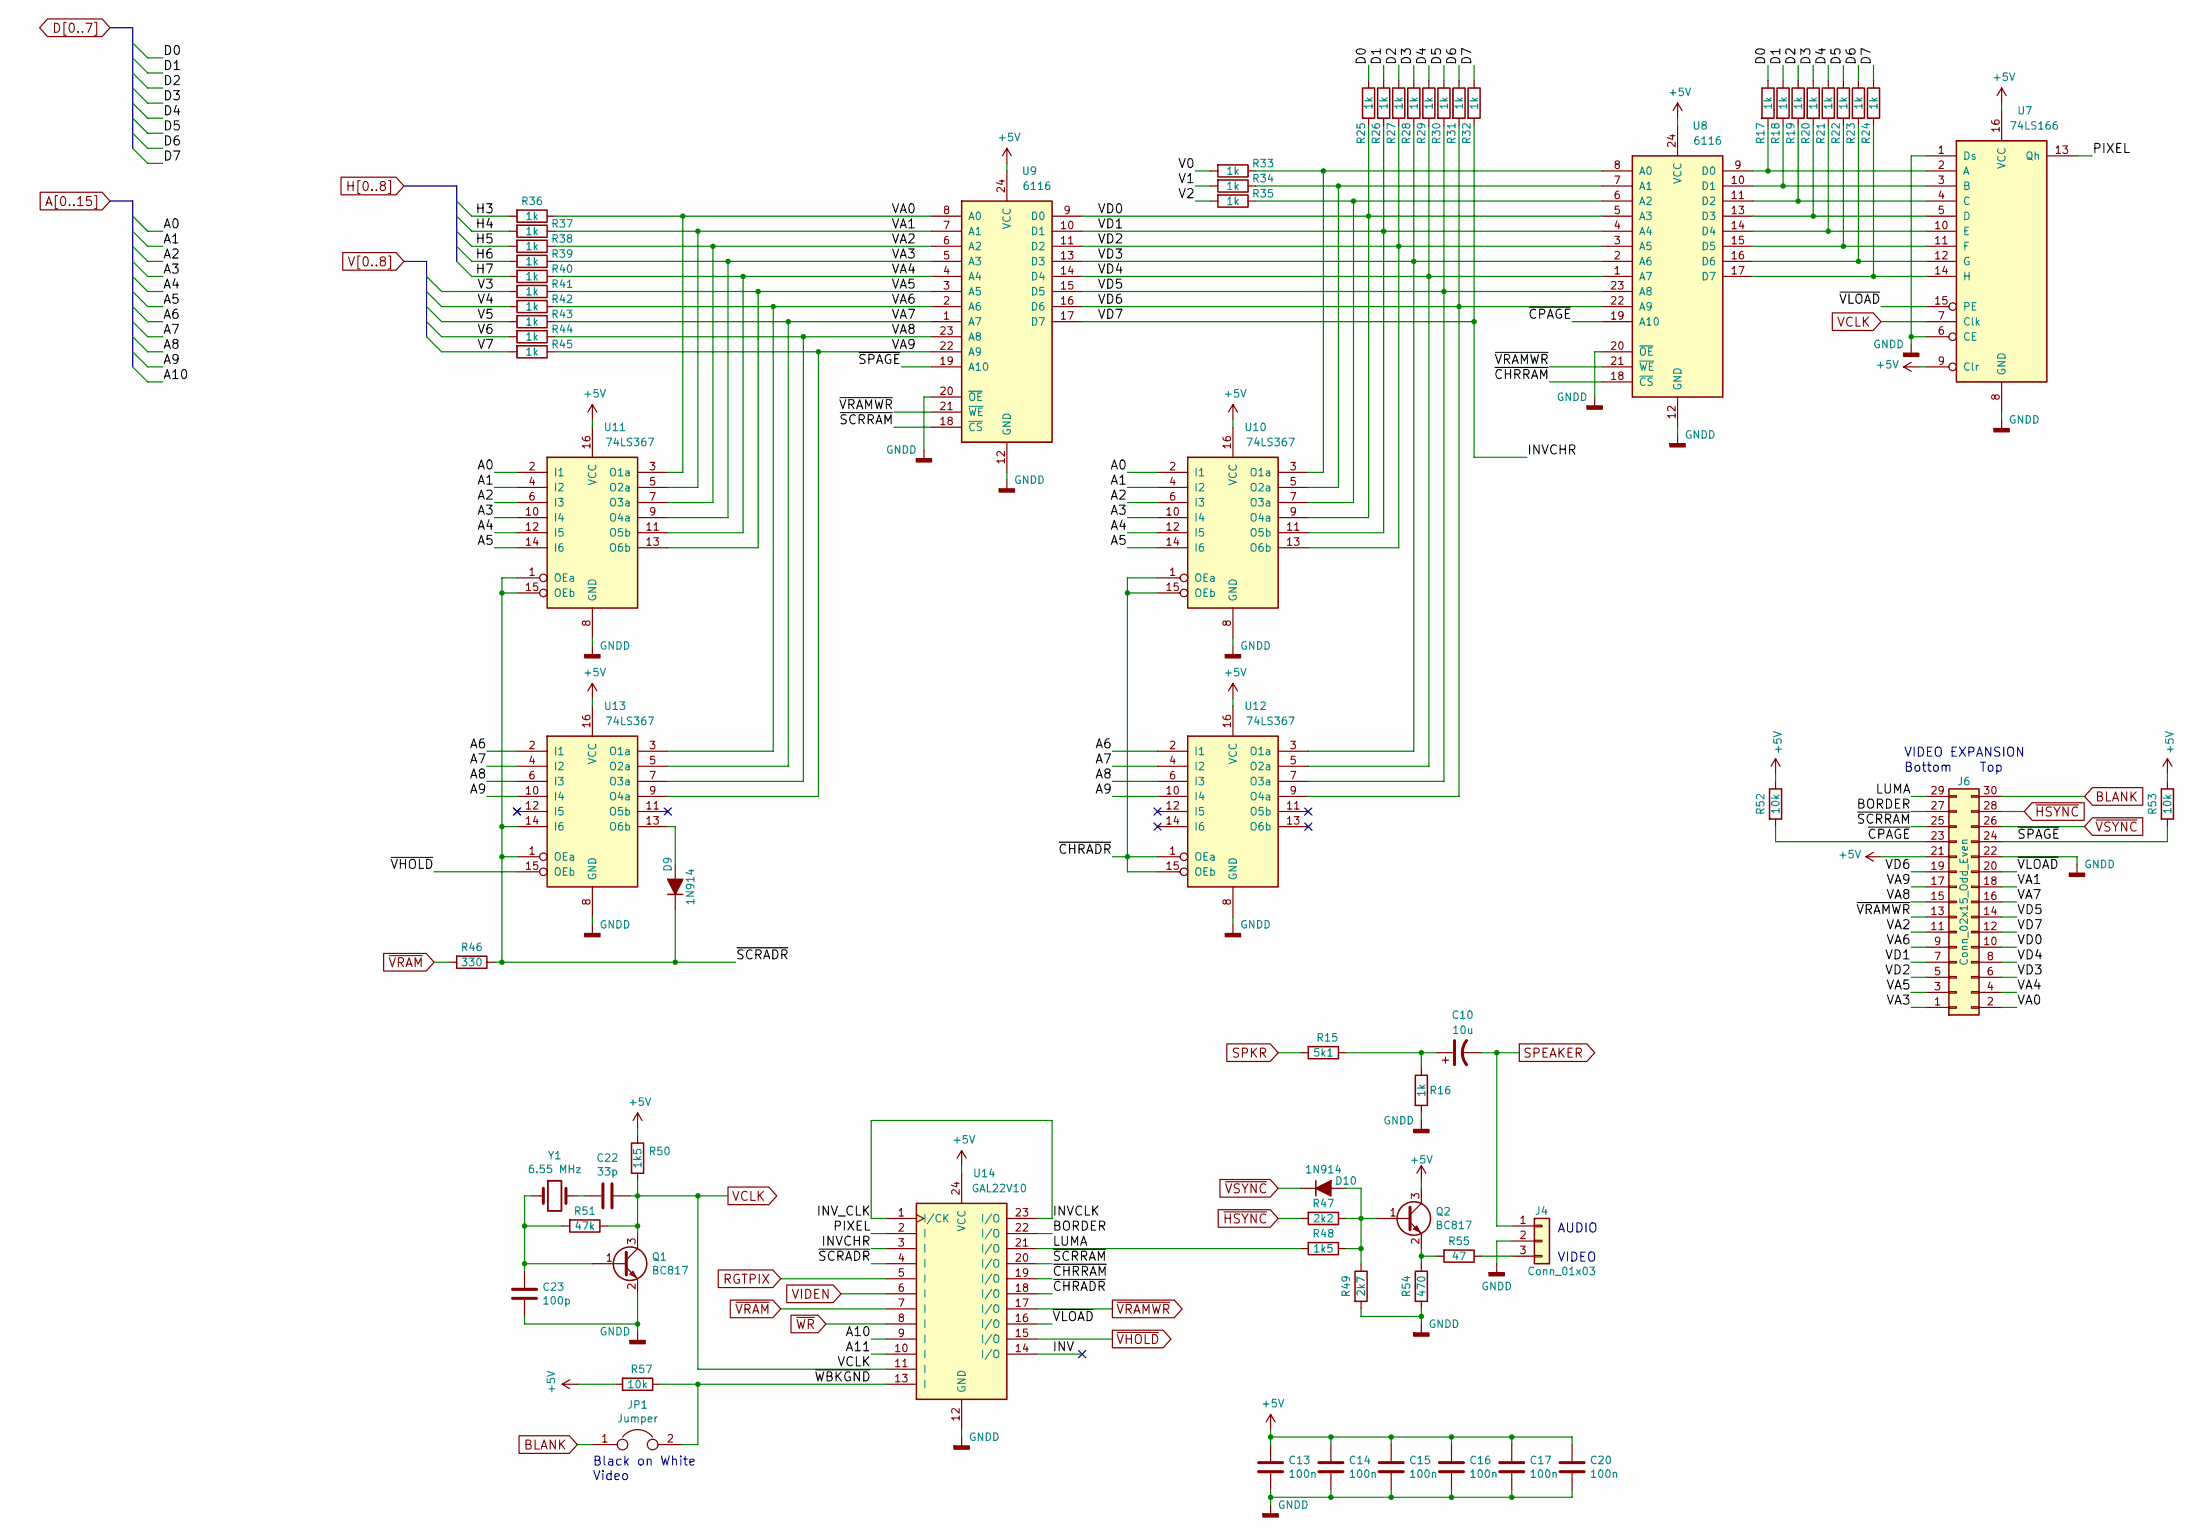
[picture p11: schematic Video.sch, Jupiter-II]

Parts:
C10: 10u; CP_Radial_D6.3mm_P2.50mm
C13, C14, C15, C16, C17, C20: 100n; C_Rect_L7.0mm_W2.5mm_P5.00mm
C22: 33p; C_0805_2012Metric_Pad1.15x1.40mm_HandSolder
C23: 100p; C_0805_2012Metric_Pad1.15x1.40mm_HandSolder
D9, D10: 1N914; D_DO-35_SOD27_P7.62mm_Horizontal
J4: Conn_01x03; Molex_KK-6410-03_03x2.54mm_Straight
J6: Conn_02x15_Odd_Even; Socket_Strip_Straight_2x15_Pitch2.54mm
JP1: Jumper; Pin_Header_Straight_1x02_Pitch2.54mm
Q1, Q2: BC817; SOT-23
R15: 5k1; R_0805_2012Metric_Pad1.15x1.40mm_HandSolder
R16, R17, R18, R19, R20, R21, R22, R23, R24, R25, R26, R27, R28, R29, R30, R31, R32, R33, R34, R35, R36, R37, R38, R39, R40, R41, R42, R43, R44, R45: 1k; R_0805_2012Metric_Pad1.15x1.40mm_HandSolder
R46: 330; R_0805_2012Metric_Pad1.15x1.40mm_HandSolder
R47: 2k2; R_0805_2012Metric_Pad1.15x1.40mm_HandSolder
R48, R50: 1k5; R_0805_2012Metric_Pad1.15x1.40mm_HandSolder
R49: 2k7; R_0805_2012Metric_Pad1.15x1.40mm_HandSolder
R51: 47k; R_0805_2012Metric_Pad1.15x1.40mm_HandSolder
R52, R53, R57: 10k; R_0805_2012Metric_Pad1.15x1.40mm_HandSolder
R54: 470; R_0805_2012Metric_Pad1.15x1.40mm_HandSolder
R55: 47; R_0805_2012Metric_Pad1.15x1.40mm_HandSolder
U7: 74LS166; DIP-16_W7.62mm
U8, U9: 6116; DIP-24_W15.24mm_Socket
U10, U11, U12, U13: 74LS367; DIP-16_W7.62mm
U14: GAL22V10; DIP-24_W7.62mm_Socket
Y1: 6.55 MHz; Crystal_HC18-U_Vertical

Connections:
+5V: C13.1, C14.1, C15.1, C16.1, C17.1, C20.1, J6.21, Q2.3 (C), R50.1, R52.1, R53.1, R57.2, U7.9 (Clr), U7.16 (VCC), U8.24 (VCC), U9.24 (VCC), U10.16 (VCC), U11.16 (VCC), U12.16 (VCC), U13.16 (VCC), U14.24 (VCC); also elsewhere on the board
/Video/BORDER: J6.27, U14.22 (I/O)
/Video/INV: U14.14 (I/O)
/Video/INVCHR: J6.12, R32.2, U9.17 (D7), U14.3 (I)
/Video/INVCLK: U14.1 (I/CK), U14.23 (I/O)
/Video/LUMA: J6.29, R48.2, U14.21 (I/O)
/Video/PIXEL: U7.13 (Qh), U14.2 (I)
/Video/VA0: J6.2, R36.1, U9.8 (A0), U11.3 (O1a)
/Video/VA1: J6.18, R37.1, U9.7 (A1), U11.5 (O2a)
/Video/VA2: J6.11, R38.1, U9.6 (A2), U11.7 (O3a)
/Video/VA3: J6.1, R39.1, U9.5 (A3), U11.9 (O4a)
/Video/VA4: J6.4, R40.1, U9.4 (A4), U11.11 (O5b)
/Video/VA5: J6.3, R41.1, U9.3 (A5), U11.13 (O6b)
/Video/VA6: J6.9, R42.1, U9.2 (A6), U13.3 (O1a)
/Video/VA7: J6.16, R43.1, U9.1 (A7), U13.5 (O2a)
/Video/VA8: J6.15, R44.1, U9.23 (A8), U13.7 (O3a)
/Video/VA9: J6.17, R45.1, U9.22 (A9), U13.9 (O4a)
/Video/VD0: J6.10, R25.2, U8.5 (A3), U9.9 (D0), U10.9 (O4a)
/Video/VD1: J6.7, R26.2, U8.4 (A4), U9.10 (D1), U10.11 (O5b)
/Video/VD2: J6.5, R27.2, U8.3 (A5), U9.11 (D2), U10.13 (O6b)
/Video/VD3: J6.6, R28.2, U8.2 (A6), U9.13 (D3), U12.3 (O1a)
/Video/VD4: J6.8, R29.2, U8.1 (A7), U9.14 (D4), U12.5 (O2a)
/Video/VD5: J6.14, R30.2, U8.23 (A8), U9.15 (D5), U12.7 (O3a)
/Video/VD6: J6.19, R31.2, U8.22 (A9), U9.16 (D6), U12.9 (O4a)
/Video/~CHRADR: U10.1 (OEa), U10.15 (OEb), U12.1 (OEa), U12.15 (OEb), U14.18 (I/O)
/Video/~CHRRAM: U8.18 (~CS), U14.19 (I/O)
/Video/~CPAGE: J6.23, R52.2, U8.19 (A10)
/Video/~SCRADR: D9.1 (K), R46.1, U11.1 (OEa), U11.15 (OEb), U13.1 (OEa), U13.14 (I6), U14.4 (I)
/Video/~SCRRAM: J6.25, U9.18 (~CS), U14.20 (I/O)
/Video/~SPAGE: J6.24, R53.2, U9.19 (A10)
/Video/~VLOAD: J6.20, U7.15 (PE), U14.16 (I/O)
/Video/~WBKGND: JP1.2, R57.1, U14.13 (I)
A0: U10.2 (I1), U11.2 (I1); also elsewhere on the board
A1: U10.4 (I2), U11.4 (I2); also elsewhere on the board
A2: U10.6 (I3), U11.6 (I3); also elsewhere on the board
A3: U10.10 (I4), U11.10 (I4); also elsewhere on the board
A4: U10.12 (I5), U11.12 (I5); also elsewhere on the board
A5: U10.14 (I6), U11.14 (I6); also elsewhere on the board
A6: U12.2 (I1), U13.2 (I1); also elsewhere on the board
A7: U12.4 (I2), U13.4 (I2); also elsewhere on the board
A8: U12.6 (I3), U13.6 (I3); also elsewhere on the board
A9: U12.10 (I4), U13.10 (I4); also elsewhere on the board
A10: U14.9 (I); also elsewhere on the board
A11: U14.10 (I); also elsewhere on the board
BLANK: J6.30, JP1.1; also elsewhere on the board
D0: R17.1, R25.1; also elsewhere on the board
D1: R18.1, R26.1; also elsewhere on the board
D2: R19.1, R27.1; also elsewhere on the board
D3: R20.1, R28.1; also elsewhere on the board
D4: R21.1, R29.1; also elsewhere on the board
D5: R22.1, R30.1; also elsewhere on the board
D6: R23.1, R31.1; also elsewhere on the board
D7: R24.1, R32.1; also elsewhere on the board
GNDD: C13.2, C14.2, C15.2, C16.2, C17.2, C20.2, C23.2, J4.2, J6.22, Q1.2 (E), R16.2, R49.2, R54.2, U7.1 (Ds), U7.6 (CE), U7.8 (GND), U8.12 (GND), U8.20 (~OE), U9.12 (GND), U9.20 (~OE), U10.8 (GND), U11.8 (GND), U12.8 (GND), U13.8 (GND), U14.12 (GND); also elsewhere on the board
H3: R36.2; also elsewhere on the board
H4: R37.2; also elsewhere on the board
H5: R38.2; also elsewhere on the board
H6: R39.2; also elsewhere on the board
H7: R40.2; also elsewhere on the board
unnamed: C10.1, R15.1, R16.1
unnamed: C22.2, Y1.2
unnamed: C23.1, Q1.1 (B), R51.2, Y1.1
unnamed: D9.2 (A), U13.13 (O6b)
unnamed: D10.2 (A), Q2.1 (B), R47.1, R48.1, R49.1
unnamed: J4.3, R55.1
unnamed: Q2.2 (E), R54.1, R55.2
unnamed: R17.2, U7.2 (A), U8.9 (D0)
unnamed: R18.2, U7.3 (B), U8.10 (D1)
unnamed: R19.2, U7.4 (C), U8.11 (D2)
unnamed: R20.2, U7.5 (D), U8.13 (D3)
unnamed: R21.2, U7.10 (E), U8.14 (D4)
unnamed: R22.2, U7.11 (F), U8.15 (D5)
unnamed: R23.2, U7.12 (G), U8.16 (D6)
unnamed: R24.2, U7.14 (H), U8.17 (D7)
unnamed: R33.1, U8.8 (A0), U10.3 (O1a)
unnamed: R34.1, U8.7 (A1), U10.5 (O2a)
unnamed: R35.1, U8.6 (A2), U10.7 (O3a)
RGTPIX: U14.5 (I); also elsewhere on the board
SPEAKER: C10.2, J4.1; also elsewhere on the board
SPKR: R15.2; also elsewhere on the board
V0: R33.2; also elsewhere on the board
V1: R34.2; also elsewhere on the board
V2: R35.2; also elsewhere on the board
V3: R41.2; also elsewhere on the board
V4: R42.2; also elsewhere on the board
V5: R43.2; also elsewhere on the board
V6: R44.2; also elsewhere on the board
V7: R45.2; also elsewhere on the board
VCLK: C22.1, Q1.3 (C), R50.2, R51.1, U7.7 (Clk), U14.11 (I); also elsewhere on the board
VIDEN: U14.6 (I); also elsewhere on the board
~HSYNC: J6.28, R47.2; also elsewhere on the board
~VHOLD: U13.15 (OEb), U14.15 (I/O); also elsewhere on the board
~VRAM: R46.2, U14.7 (I); also elsewhere on the board
~VRAMWR: J6.13, U8.21 (~WE), U9.21 (~WE), U14.17 (I/O); also elsewhere on the board
~VSYNC: D10.1 (K), J6.26; also elsewhere on the board
~WR: U14.8 (I); also elsewhere on the board

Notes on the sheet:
AUDIO VIDEO
Bottom Top
VIDEO EXPANSION
Black on White Video

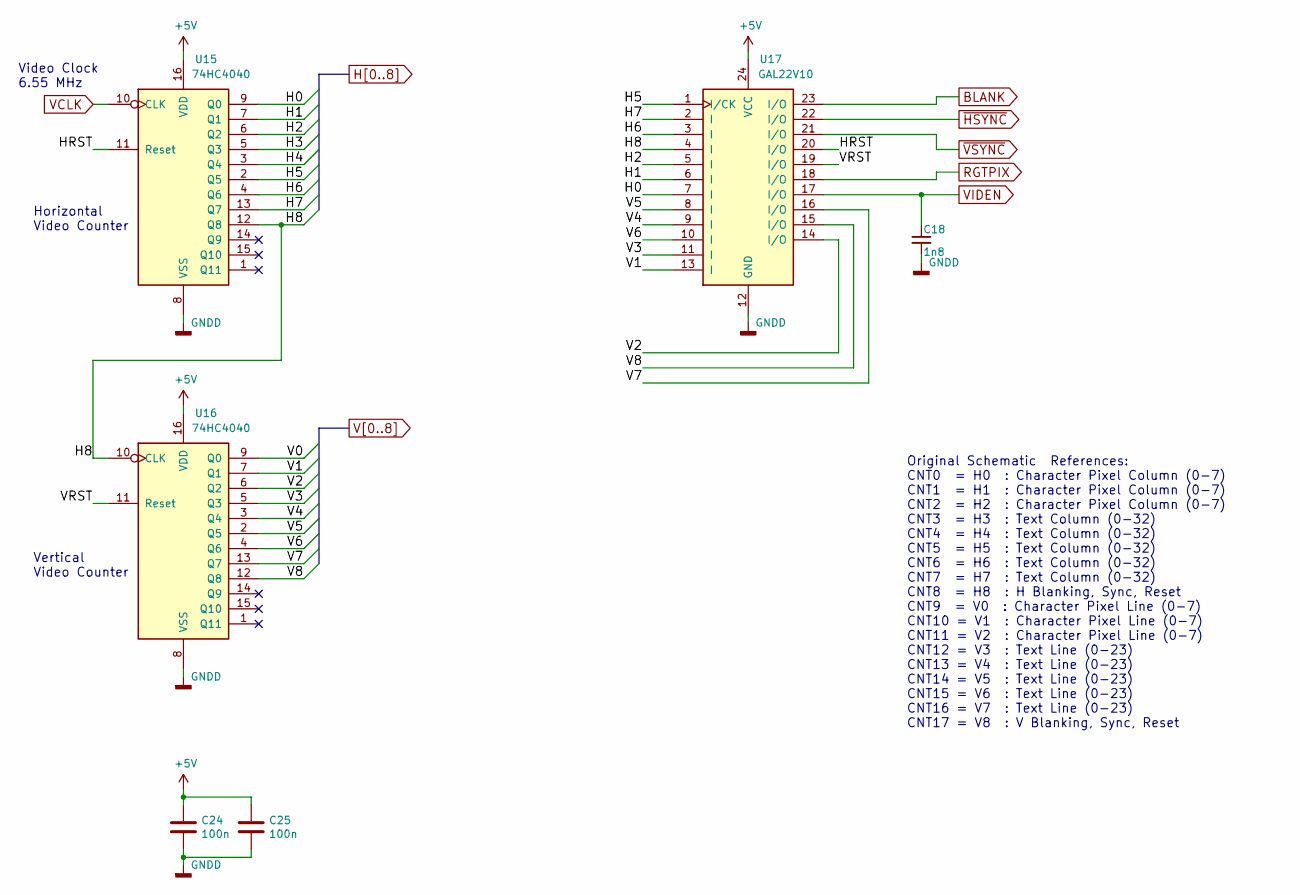
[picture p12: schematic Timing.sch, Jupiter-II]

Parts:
C18: 1n8; C_0805_2012Metric_Pad1.15x1.40mm_HandSolder
C24, C25: 100n; C_Rect_L7.0mm_W2.5mm_P5.00mm
U15, U16: 74HC4040; DIP-16_W7.62mm
U17: GAL22V10; DIP-24_W7.62mm_Socket

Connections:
+5V: C24.1, C25.1, U15.16 (VDD), U16.16 (VDD), U17.24 (VCC); also elsewhere on the board
/Timing/HRST: U15.11 (Reset), U17.20 (I/O)
/Timing/VRST: U16.11 (Reset), U17.19 (I/O)
BLANK: U17.23 (I/O); also elsewhere on the board
GNDD: C18.2, C24.2, C25.2, U15.8 (VSS), U16.8 (VSS), U17.12 (GND); also elsewhere on the board
H0: U15.9 (Q0), U17.7 (I); also elsewhere on the board
H1: U15.7 (Q1), U17.6 (I)
H2: U15.6 (Q2), U17.5 (I)
H3: U15.5 (Q3); also elsewhere on the board
H4: U15.3 (Q4); also elsewhere on the board
H5: U15.2 (Q5), U17.1 (I/CK); also elsewhere on the board
H6: U15.4 (Q6), U17.3 (I); also elsewhere on the board
H7: U15.13 (Q7), U17.2 (I); also elsewhere on the board
H8: U15.12 (Q8), U16.10 (CLK), U17.4 (I)
RGTPIX: U17.18 (I/O); also elsewhere on the board
V0: U16.9 (Q0); also elsewhere on the board
V1: U16.7 (Q1), U17.13 (I); also elsewhere on the board
V2: U16.6 (Q2), U17.14 (I/O); also elsewhere on the board
V3: U16.5 (Q3), U17.11 (I); also elsewhere on the board
V4: U16.3 (Q4), U17.9 (I); also elsewhere on the board
V5: U16.2 (Q5), U17.8 (I); also elsewhere on the board
V6: U16.4 (Q6), U17.10 (I); also elsewhere on the board
V7: U16.13 (Q7), U17.16 (I/O); also elsewhere on the board
V8: U16.12 (Q8), U17.15 (I/O)
VCLK: U15.10 (CLK); also elsewhere on the board
VIDEN: C18.1, U17.17 (I/O); also elsewhere on the board
~HSYNC: U17.22 (I/O); also elsewhere on the board
~VSYNC: U17.21 (I/O); also elsewhere on the board

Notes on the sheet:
Video Clock 6.55 MHz
Horizontal Video Counter
Vertical Video Counter
Original Schematic References: CNT0 = H0 : Character Pixel Column (0-7) CNT1 = H1 : Character Pixel Column (0-7) CNT2 = H2 : Character Pixel Column (0-7) CNT3 = H3 : Text Column (0-32) CNT4 = H4 : Text Column (0-32) CNT5 = H5 : Text Column (0-32) CNT6 = H6 : Text Column (0-32) CNT7 = H7 : Text Colu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

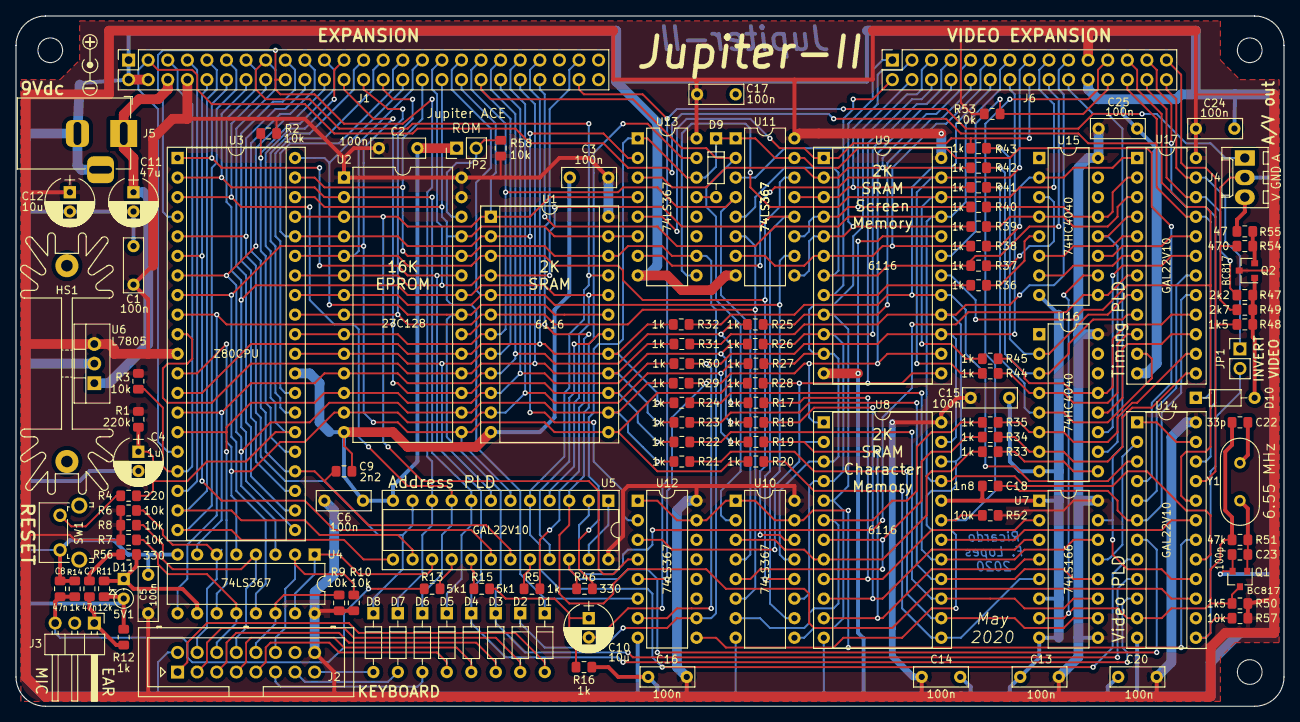
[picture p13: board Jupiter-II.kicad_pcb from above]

Board: 2 copper layers, 164.5 x 89.5 mm, 126 parts (0 on the bottom side), 144 nets.

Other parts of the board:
REF01: Symbol_Barrel_Polarity

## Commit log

2020-04-06 Initial Release
    [Jupiter-II-B_Mask.gbr, Jupiter-II-B_SilkS.gbr, Jupiter-II-Bottom.gbr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]
2020-05-11 Making it work
    Corrected U4 (74LS367) swapped i/o lines
    Improved video output circuit
    Optimized audio circuit component values
    Modified Mic output circuit
    Corrected Silk screen swapped labels "R1" and "R3"
    [Jupiter-II.kicad_pcb]
2020-05-11 Gerbers reflecting updated PCB layout
    [Jupiter-II-B_Mask.gbr, Jupiter-II-B_SilkS.gbr, Jupiter-II-Bottom.gbr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]
2020-05-17 Silk screen layer updated
    [Jupiter-II_keyboard-B_Mask.gbr, Jupiter-II_keyboard-B_SilkS.gbr, Jupiter-II_keyboard-Back.gbr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]
2020-05-17 Inverted video option
    [Jupiter-II-B_Mask.gbr, Jupiter-II-B_SilkS.gbr, Jupiter-II-Bottom.gbr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]
2020-05-18 Removing video glitches
    Glitches occurs on VIDEN and WAIT lines due to the use of asynchronous counters 74HC4040 (the same occurs when using the 74LS393). Those gliteches are usually controlled by a filtering capacitor in the WAIT line. Here a capacitor was also included at the VIDEN line before WAIT signal generation.
    Those glitches can be seen as image interference on screen while the CPU are accessing video memory.
    [Jupiter-II.kicad_pcb, Timing.sch]
2020-05-18 Update reflecting PCB changes
    [Jupiter-II-B_Mask.gbr, Jupiter-II-B_SilkS.gbr, Jupiter-II-Bottom.gbr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]
2020-06-16 Video improvement (#6)
    * Preparing for expansion
    * PLD update for expansion
    * PLD update
    [Jupiter-II.kicad_pcb, Jupiter-II.sch, Timing.sch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]
2020-06-16 Keyboard redimensioning (#7)
    * Resizing Board
    * production gerbers
    [Jupiter-II_keyboard-B_Mask.gbr, Jupiter-II_keyboard-B_SilkS.gbr, Jupiter-II_keyboard-Back.gbr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]
2020-06-16 production gerbers (#8)
    [Jupiter-II-B_Mask.gbr, Jupiter-II-B_SilkS.gbr, Jupiter-II-Bottom.gbr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]
2020-10-06 Added llibrary
    Added missing livrary and PDF schematic
2021-11-14 Update README.md (#10)
    https://forum.kicad.info/t/warning-avoid-all-links-to-kicad-pcb-org-use-kicad-org/31521
